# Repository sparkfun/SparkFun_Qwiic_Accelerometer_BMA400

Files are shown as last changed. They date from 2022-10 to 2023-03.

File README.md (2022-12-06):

SparkFun Triple Axis Accelerometer Breakout - BMA400 (Qwiic) 
============================================================

<table class="table table-striped table-bordered"?
  <tr align="center">
    <td><a href="https://www.sparkfun.com/products/21208">SparkFun Triple Axis Accelerometer Breakout - BMA400 (Qwiic)</a></td>
    <td><a href="https://www.sparkfun.com/products/21207">SparkFun Micro Triple Axis Accelerometer Breakout - BMA400 (Qwiic)</a></td>
  </tr>
  <tr align="center">
    <td><a href="https://www.sparkfun.com/products/21208"><i>SparkFun Triple Axis Accelerometer Breakout - BMA400 (Qwiic)</i></a></td>
    <td><a href="https://www.sparkfun.com/products/21207"><i>SparkFun Micro Triple Axis Accelerometer Breakout - BMA400 (Qwiic)</i></a></td>
  </tr>
</table>

The SparkFun Qwiic BMA400 Triple Axis Accelerometer Breakout offers a 3-axis acceleration sensor perfect for ultra-low-power applications on an easy-to-use Qwiic breakout board. Dubbed the first "real" ultra-low power acceleration sensor, the BMA400 is perfect when used in both wearable and smart home applications. Where this sensor shines, however, is its ability to distinguish between critical situations and false signals by avoiding false alarms. The Qwiic system allows for integration into your I<sup>2</sup>C system with no soldering required. This Qwiic breakout also includes 0.1"-spaced PTH pins connected to the sensor's communication interface and interrupt pins for applications that require a traditional soldered connection.

The BMA400 from Bosch Sensortech<sup>&copy;</sup> has a full-scale acceleration range of &plusmn;2/&plusmn;4/&plusmn;8/&plusmn;16g with exceptionally low current consumption of < 14.5&micro;A while operating at its highest performance settings. The sensor also includes a complete feature set for on-chip interrupts including auto wakeup/low power, step counter, activity recognition, orientation detection, and tap/double tap. 

Repository Contents
-------------------
* **/Documents** - Datasheet
* **/Hardware** - Eagle design files (.brd, .sch)
* **/Production** - Production panel files (.brd)

Documentation
-------------
* **[Hookup Guide](https://learn.sparkfun.com/tutorials/sparkfun-triple-axis-accelerometer-breakout---bma400-qwiic-hookup-guide)** - Basic Hookup Guide for the SparkFun Triple Axis Accelerometer Breakout - BMA400 (Qwiic). 
* **[BMA400 Arduino Library](https://github.com/sparkfun/SparkFun_BMA400_Arduino_Library)** - Arduino library for the BMA400 based off the Bosch API.

Product Versions
----------------
* [SEN-21208](https://www.sparkfun.com/products/21208) - Standard Size Initial Release.
* [SEN-21207](https://www.sparkfun.com/products/21207) - Micro Size Initial Release.

License Information
-------------------

This product is _**open source**_! 

Please review the LICENSE.md file for license information.

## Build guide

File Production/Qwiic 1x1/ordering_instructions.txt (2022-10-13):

panel size, 169x117mm
PCB thickness, 1.6mm
number of layers, 2
soldermask color, Red
silkscreen color, White
oz copper, 1oz
finish, HASL lead free
stencils, top
pcs per panel, 24
min trace width, 0.2032mm / 0.0080in
min drill size, 0.3048mm / 0.0120in

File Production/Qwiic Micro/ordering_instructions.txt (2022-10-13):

panel size, 79x170mm
PCB thickness, 1.6mm
number of layers, 2
soldermask color, Red
silkscreen color, White
oz copper, 1oz
finish, HASL lead free
stencils, top
pcs per panel, 64
min trace width, 0.1270mm / 0.0050in
min drill size, 0.3048mm / 0.0120in

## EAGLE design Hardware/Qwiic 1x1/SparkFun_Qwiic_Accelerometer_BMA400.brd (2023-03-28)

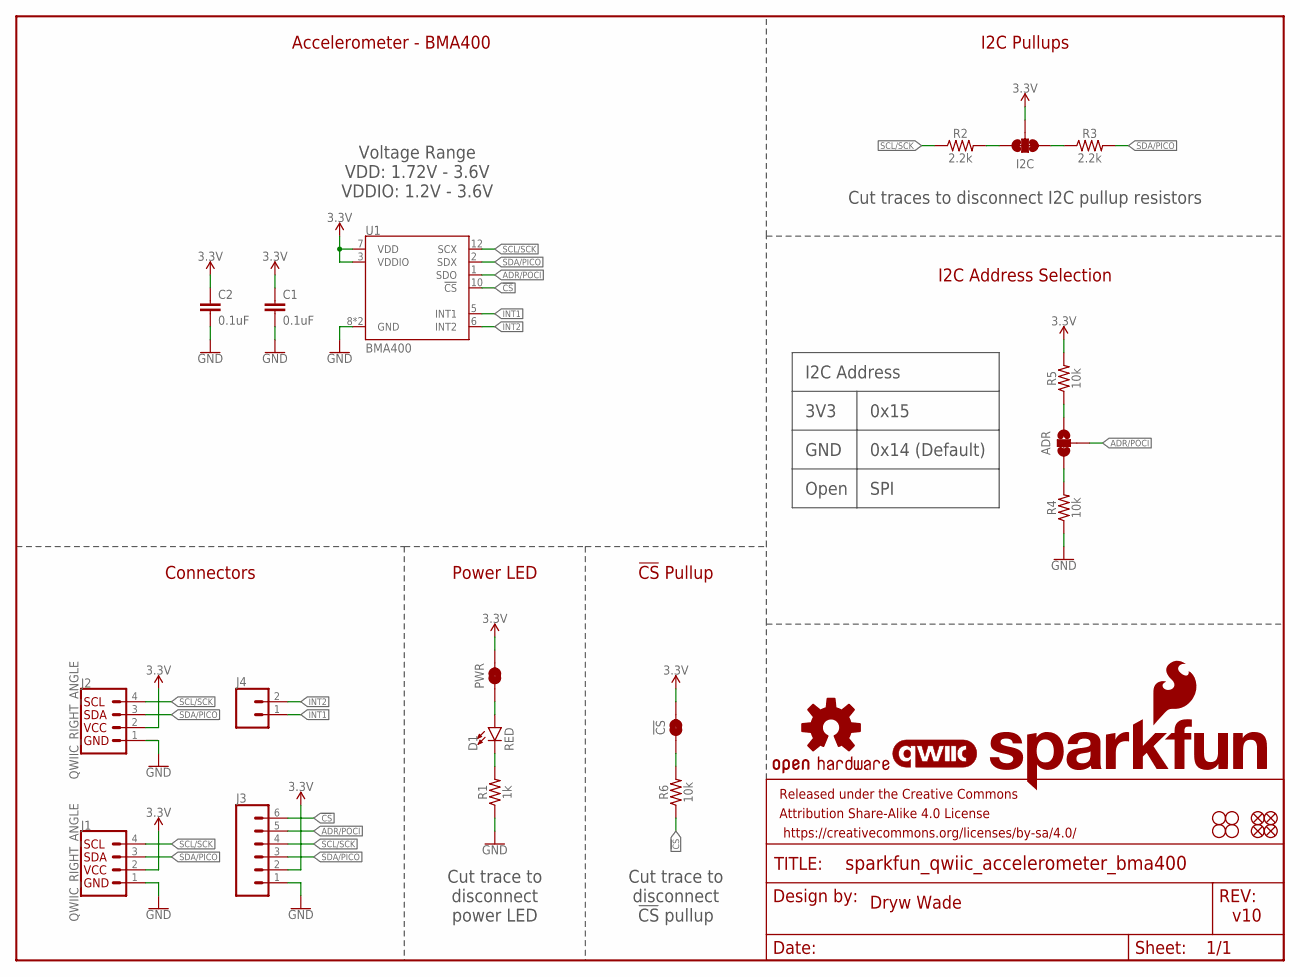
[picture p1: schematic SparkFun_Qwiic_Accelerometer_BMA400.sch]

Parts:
!CS!: JUMPER-SMT_2_NC_TRACE_SILK; SMT-JUMPER_2_NC_TRACE_SILK
ADR: JUMPER-SMT_3_1-NC_TRACE_SILK; SMT-JUMPER_3_1-NC_TRACE_SILK
C1, C2: 0.1uF; 0603
D1: RED; LED-0603
FD1, FD2, FD3, FD4: FIDUCIAL1X2; FIDUCIAL-1X2
FRAME1: FRAME-LETTER; CREATIVE_COMMONS
H1, H2, H3, H4: STAND-OFF
I2C: JUMPER-SMT_3_2-NC_TRACE_SILK; SMT-JUMPER_3_2-NC_TRACE_SILK
J1, J2: QWIIC_RIGHT_ANGLE; JST04_1MM_RA
J3: CONN_06NO_SILK_NO_POP; 1X06_NO_SILK
J4: CONN_021X02_NO_SILK; 1X02_NO_SILK
LOGO1: QWIIC_LOGO_5MM; QWIIC_5MM
LOGO2: SFE_LOGO_NAME_FLAME.1_INCH; SFE_LOGO_NAME_FLAME_.1
LOGO3: OSHW-LOGOS; OSHW-LOGO-S
PWR: JUMPER-SMT_2_NC_TRACE_SILK; SMT-JUMPER_2_NC_TRACE_SILK
R1: 1k; 0603
R2, R3: 2.2k; 0603
R4, R5, R6: 10k; 0603
U1: BMA400

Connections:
3.3V: !CS!.2, C1.1, C2.1, I2C.2, J1.2, J2.2, J3.2, PWR.2, R5.2, U1.3 (VDDIO), U1.7 (VDD)
!CS!: J3.6, R6.1, U1.10 (!CS!)
ADR/POCI: ADR.2, J3.5, U1.1 (SDO)
GND: C1.2, C2.2, J1.1, J2.1, J3.1, R1.1, R4.1, U1.8 (GND), U1.9 (GND)
INT1: J4.1, U1.5 (INT1)
INT2: J4.2, U1.6 (INT2)
unnamed: D1.A, PWR.1
unnamed: D1.C, R1.2
unnamed: I2C.3, R2.2
unnamed: I2C.1, R3.1
unnamed: ADR.1, R5.1
unnamed: ADR.3, R4.2
unnamed: !CS!.1, R6.2
SCL/SCK: J1.4, J2.4, J3.4, R2.1, U1.12 (SCX)
SDA/PICO: J1.3, J2.3, J3.3, R3.2, U1.2 (SDX)

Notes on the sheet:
Dryw Wade
v10
Accelerometer - BMA400
Connectors
Power LED
I2C Pullups
I2C Address Selection
I2C Address
GND
3V3
Open
0x15
0x14 (Default)
SPI
Cut traces to disconnect I2C pullup resistors
Cut trace to disconnect power LED
!CS! Pullup
Cut trace to disconnect !CS! pullup
Voltage Range VDD: 1.72V - 3.6V VDDIO: 1.2V - 3.6V

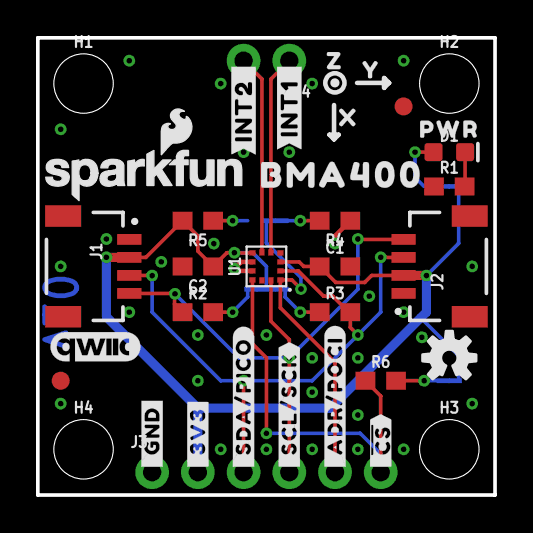
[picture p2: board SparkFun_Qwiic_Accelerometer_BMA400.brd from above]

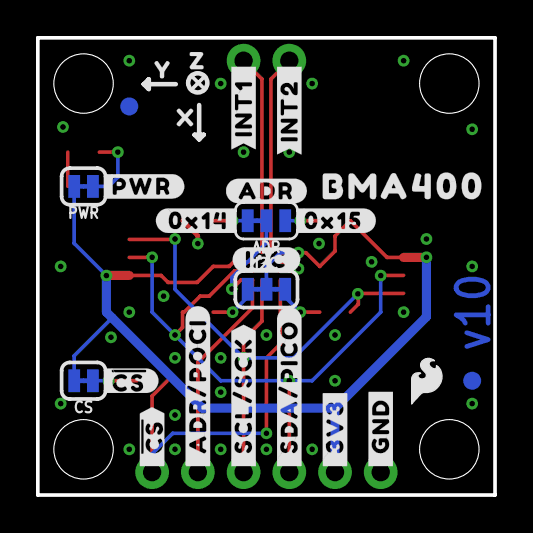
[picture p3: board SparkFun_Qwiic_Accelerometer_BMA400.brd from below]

Board: 2 copper layers, 25.4 x 25.4 mm, 62 parts (25 on the bottom side), 15 nets.

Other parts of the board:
U$1: PWR0
U$2, U$34: X2114
U$3, U$35: Y2115
U$4, U$20: #INT1_#0
U$5, U$21: #INT2_#0
U$6: #_3V3#6
U$7: #_SDA#PICO#5
U$8: #_#CS##2
U$9: #_SCL#SCK#3
U$10: #_GND#0
U$11: #_3V3#0
U$12: #_SDA#PICO#0
U$13: #_SCL#SCK#0
U$14: #_ADR#POCI#0
U$15: #_#CS##0
U$16: #I2C#0
U$17: #ADR#0
U$18: #0X15#0
U$19: #0X14#0
U$22: #PWR#0
U$23, U$24: BMA4000
U$25: ##CS##0
U$26: SFE_LOGO_FLAME_.1
U$27: #_ADR#POCI#1
U$28: #_GND#6
U$29, U$36: Z2116

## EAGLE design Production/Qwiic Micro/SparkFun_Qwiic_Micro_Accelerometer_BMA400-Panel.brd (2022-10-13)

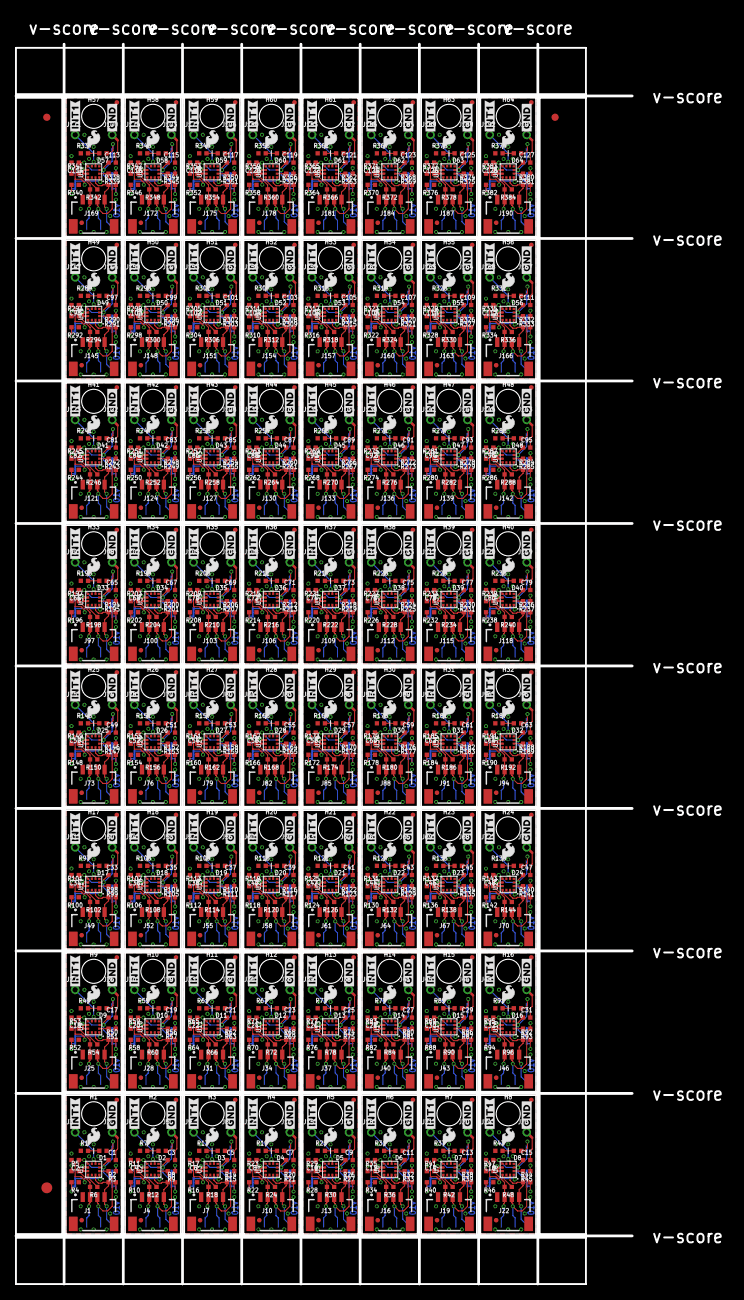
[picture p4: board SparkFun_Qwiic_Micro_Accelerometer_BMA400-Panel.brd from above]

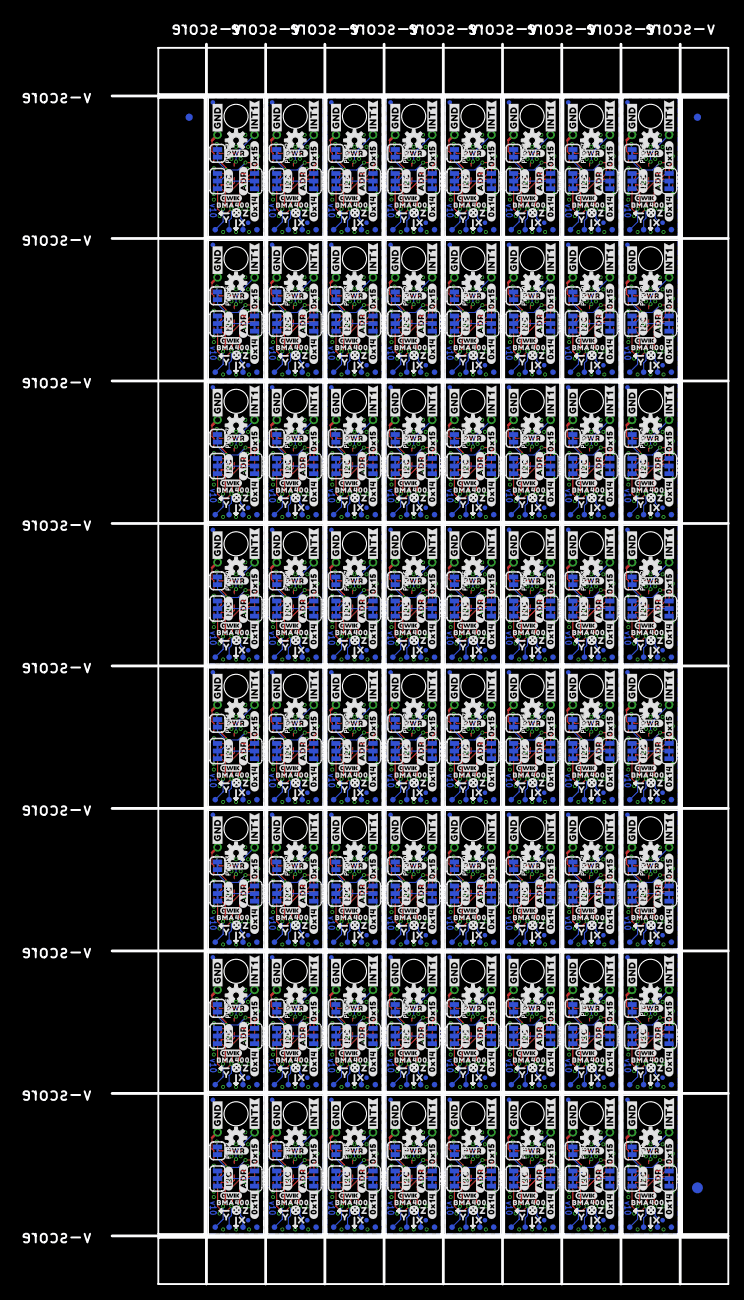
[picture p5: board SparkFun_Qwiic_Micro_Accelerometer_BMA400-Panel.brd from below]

Board: 2 copper layers, 84.6 x 170.2 mm, 2758 parts (1411 on the bottom side), 832 nets.

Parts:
ADR, ADR1, ADR2, ADR3, ADR4, ADR5, ADR6, ADR7, ADR8, ADR9, ADR10, ADR11, ADR12, ADR13, ADR14, ADR15, ADR16, ADR17, ADR18, ADR19, ADR20, ADR21, ADR22, ADR23, ADR24, ADR25, ADR26, ADR27, ADR28, ADR29, ADR30, ADR31, ADR32, ADR33, ADR34, ADR35, ADR36, ADR37, ADR38, ADR39, ADR40, ADR41, ADR42, ADR43, ADR44, ADR45, ADR46, ADR47, ADR48, ADR49, ADR50, ADR51, ADR52, ADR53, ADR54, ADR55, ADR56, ADR57, ADR58, ADR59, ADR60, ADR61, ADR62, ADR63: JUMPER-SMT_3_1-NC_TRACE_SILK; SMT-JUMPER_3_1-NC_TRACE_SILK
C1, C2, C3, C4, C5, C6, C7, C8, C9, C10, C11, C12, C13, C14, C15, C16, C17, C18, C19, C20, C21, C22, C23, C24, C25, C26, C27, C28, C29, C30, C31, C32, C33, C34, C35, C36, C37, C38, C39, C40, C41, C42, C43, C44, C45, C46, C47, C48, C49, C50, C51, C52, C53, C54, C55, C56, C57, C58, C59, C60, C61, C62, C63, C64, C65, C66, C67, C68, C69, C70, C71, C72, C73, C74, C75, C76, C77, C78, C79, C80, C81, C82, C83, C84, C85, C86, C87, C88, C89, C90, C91, C92, C93, C94, C95, C96, C97, C98, C99, C100, C101, C102, C103, C104, C105, C106, C107, C108, C109, C110, C111, C112, C113, C114, C115, C116, C117, C118, C119, C120, C121, C122, C123, C124, C125, C126, C127, C128: 0.1uF; 0402-TIGHT
D1, D2, D3, D4, D5, D6, D7, D8, D9, D10, D11, D12, D13, D14, D15, D16, D17, D18, D19, D20, D21, D22, D23, D24, D25, D26, D27, D28, D29, D30, D31, D32, D33, D34, D35, D36, D37, D38, D39, D40, D41, D42, D43, D44, D45, D46, D47, D48, D49, D50, D51, D52, D53, D54, D55, D56, D57, D58, D59, D60, D61, D62, D63, D64: RED; LED-0402
E$1, E$2, E$3, E$4: FIDUCIAL-1X2
E$5, E$6: FIDUCIAL-1.5X3
FD1, FD2, FD3, FD4, FD5, FD6, FD7, FD8, FD9, FD10, FD11, FD12, FD13, FD14, FD15, FD16, FD17, FD18, FD19, FD20, FD21, FD22, FD23, FD24, FD25, FD26, FD27, FD28, FD29, FD30, FD31, FD32, FD33, FD34, FD35, FD36, FD37, FD38, FD39, FD40, FD41, FD42, FD43, FD44, FD45, FD46, FD47, FD48, FD49, FD50, FD51, FD52, FD53, FD54, FD55, FD56, FD57, FD58, FD59, FD60, FD61, FD62, FD63, FD64, FD65, FD66, FD67, FD68, FD69, FD70, FD71, FD72, FD73, FD74, FD75, FD76, FD77, FD78, FD79, FD80, FD81, FD82, FD83, FD84, FD85, FD86, FD87, FD88, FD89, FD90, FD91, FD92, FD93, FD94, FD95, FD96, FD97, FD98, FD99, FD100, FD101, FD102, FD103, FD104, FD105, FD106, FD107, FD108, FD109, FD110, FD111, FD112, FD113, FD114, FD115, FD116, FD117, FD118, FD119, FD120, FD121, FD122, FD123, FD124, FD125, FD126, FD127, FD128, FD129, FD130, FD131, FD132, FD133, FD134, FD135, FD136, FD137, FD138, FD139, FD140, FD141, FD142, FD143, FD144, FD145, FD146, FD147, FD148, FD149, FD150, FD151, FD152, FD153, FD154, FD155, FD156, FD157, FD158, FD159, FD160, FD161, FD162, FD163, FD164, FD165, FD166, FD167, FD168, FD169, FD170, FD171, FD172, FD173, FD174, FD175, FD176, FD177, FD178, FD179, FD180, FD181, FD182, FD183, FD184, FD185, FD186, FD187, FD188, FD189, FD190, FD191, FD192, FD193, FD194, FD195, FD196, FD197, FD198, FD199, FD200, FD201, FD202, FD203, FD204, FD205, FD206, FD207, FD208, FD209, FD210, FD211, FD212, FD213, FD214, FD215, FD216, FD217, FD218, FD219, FD220, FD221, FD222, FD223, FD224, FD225, FD226, FD227, FD228, FD229, FD230, FD231, FD232, FD233, FD234, FD235, FD236, FD237, FD238, FD239, FD240, FD241, FD242, FD243, FD244, FD245, FD246, FD247, FD248, FD249, FD250, FD251, FD252, FD253, FD254, FD255, FD256: FIDUCIALUFIDUCIAL; FIDUCIAL-MICRO
FRAME1, FRAME2, FRAME3, FRAME4, FRAME5, FRAME6, FRAME7, FRAME8, FRAME9, FRAME10, FRAME11, FRAME12, FRAME13, FRAME14, FRAME15, FRAME16, FRAME17, FRAME18, FRAME19, FRAME20, FRAME21, FRAME22, FRAME23, FRAME24, FRAME25, FRAME26, FRAME27, FRAME28, FRAME29, FRAME30, FRAME31, FRAME32, FRAME33, FRAME34, FRAME35, FRAME36, FRAME37, FRAME38, FRAME39, FRAME40, FRAME41, FRAME42, FRAME43, FRAME44, FRAME45, FRAME46, FRAME47, FRAME48, FRAME49, FRAME50, FRAME51, FRAME52, FRAME53, FRAME54, FRAME55, FRAME56, FRAME57, FRAME58, FRAME59, FRAME60, FRAME61, FRAME62, FRAME63, FRAME64: FRAME-LETTER; CREATIVE_COMMONS
H1, H2, H3, H4, H5, H6, H7, H8, H9, H10, H11, H12, H13, H14, H15, H16, H17, H18, H19, H20, H21, H22, H23, H24, H25, H26, H27, H28, H29, H30, H31, H32, H33, H34, H35, H36, H37, H38, H39, H40, H41, H42, H43, H44, H45, H46, H47, H48, H49, H50, H51, H52, H53, H54, H55, H56, H57, H58, H59, H60, H61, H62, H63, H64: STAND-OFF
I2C, I2C1, I2C2, I2C3, I2C4, I2C5, I2C6, I2C7, I2C8, I2C9, I2C10, I2C11, I2C12, I2C13, I2C14, I2C15, I2C16, I2C17, I2C18, I2C19, I2C20, I2C21, I2C22, I2C23, I2C24, I2C25, I2C26, I2C27, I2C28, I2C29, I2C30, I2C31, I2C32, I2C33, I2C34, I2C35, I2C36, I2C37, I2C38, I2C39, I2C40, I2C41, I2C42, I2C43, I2C44, I2C45, I2C46, I2C47, I2C48, I2C49, I2C50, I2C51, I2C52, I2C53, I2C54, I2C55, I2C56, I2C57, I2C58, I2C59, I2C60, I2C61, I2C62, I2C63: JUMPER-SMT_3_2-NC_TRACE_SILK; SMT-JUMPER_3_2-NC_TRACE_SILK
J1, J4, J7, J10, J13, J16, J19, J22, J25, J28, J31, J34, J37, J40, J43, J46, J49, J52, J55, J58, J61, J64, J67, J70, J73, J76, J79, J82, J85, J88, J91, J94, J97, J100, J103, J106, J109, J112, J115, J118, J121, J124, J127, J130, J133, J136, J139, J142, J145, J148, J151, J154, J157, J160, J163, J166, J169, J172, J175, J178, J181, J184, J187, J190: QWIIC_RIGHT_ANGLE; JST04_1MM_RA
J2, J3, J5, J6, J8, J9, J11, J12, J14, J15, J17, J18, J20, J21, J23, J24, J26, J27, J29, J30, J32, J33, J35, J36, J38, J39, J41, J42, J44, J45, J47, J48, J50, J51, J53, J54, J56, J57, J59, J60, J62, J63, J65, J66, J68, J69, J71, J72, J74, J75, J77, J78, J80, J81, J83, J84, J86, J87, J89, J90, J92, J93, J95, J96, J98, J99, J101, J102, J104, J105, J107, J108, J110, J111, J113, J114, J116, J117, J119, J120, J122, J123, J125, J126, J128, J129, J131, J132, J134, J135, J137, J138, J140, J141, J143, J144, J146, J147, J149, J150, J152, J153, J155, J156, J158, J159, J161, J162, J164, J165, J167, J168, J170, J171, J173, J174, J176, J177, J179, J180, J182, J183, J185, J186, J188, J189, J191, J192: 1X01_1MM_NO_SILK
LOGO1, LOGO5, LOGO9, LOGO13, LOGO17, LOGO21, LOGO25, LOGO29, LOGO33, LOGO37, LOGO41, LOGO45, LOGO49, LOGO53, LOGO57, LOGO61, LOGO65, LOGO69, LOGO73, LOGO77, LOGO81, LOGO85, LOGO89, LOGO93, LOGO97, LOGO101, LOGO105, LOGO109, LOGO113, LOGO117, LOGO121, LOGO125, LOGO129, LOGO133, LOGO137, LOGO141, LOGO145, LOGO149, LOGO153, LOGO157, LOGO161, LOGO165, LOGO169, LOGO173, LOGO177, LOGO181, LOGO185, LOGO189, LOGO193, LOGO197, LOGO201, LOGO205, LOGO209, LOGO213, LOGO217, LOGO221, LOGO225, LOGO229, LOGO233, LOGO237, LOGO241, LOGO245, LOGO249, LOGO253: QWIIC_LOGO_3MM; QWIIC_3MM
LOGO2, LOGO6, LOGO10, LOGO14, LOGO18, LOGO22, LOGO26, LOGO30, LOGO34, LOGO38, LOGO42, LOGO46, LOGO50, LOGO54, LOGO58, LOGO62, LOGO66, LOGO70, LOGO74, LOGO78, LOGO82, LOGO86, LOGO90, LOGO94, LOGO98, LOGO102, LOGO106, LOGO110, LOGO114, LOGO118, LOGO122, LOGO126, LOGO130, LOGO134, LOGO138, LOGO142, LOGO146, LOGO150, LOGO154, LOGO158, LOGO162, LOGO166, LOGO170, LOGO174, LOGO178, LOGO182, LOGO186, LOGO190, LOGO194, LOGO198, LOGO202, LOGO206, LOGO210, LOGO214, LOGO218, LOGO222, LOGO226, LOGO230, LOGO234, LOGO238, LOGO242, LOGO246, LOGO250, LOGO254: SFE_LOGO_NAMEBLANK; BLANK
LOGO3, LOGO7, LOGO11, LOGO15, LOGO19, LOGO23, LOGO27, LOGO31, LOGO35, LOGO39, LOGO43, LOGO47, LOGO51, LOGO55, LOGO59, LOGO63, LOGO67, LOGO71, LOGO75, LOGO79, LOGO83, LOGO87, LOGO91, LOGO95, LOGO99, LOGO103, LOGO107, LOGO111, LOGO115, LOGO119, LOGO123, LOGO127, LOGO131, LOGO135, LOGO139, LOGO143, LOGO147, LOGO151, LOGO155, LOGO159, LOGO163, LOGO167, LOGO171, LOGO175, LOGO179, LOGO183, LOGO187, LOGO191, LOGO195, LOGO199, LOGO203, LOGO207, LOGO211, LOGO215, LOGO219, LOGO223, LOGO227, LOGO231, LOGO235, LOGO239, LOGO243, LOGO247, LOGO251, LOGO255: OSHW-LOGOS; OSHW-LOGO-S
LOGO4, LOGO8, LOGO12, LOGO16, LOGO20, LOGO24, LOGO28, LOGO32, LOGO36, LOGO40, LOGO44, LOGO48, LOGO52, LOGO56, LOGO60, LOGO64, LOGO68, LOGO72, LOGO76, LOGO80, LOGO84, LOGO88, LOGO92, LOGO96, LOGO100, LOGO104, LOGO108, LOGO112, LOGO116, LOGO120, LOGO124, LOGO128, LOGO132, LOGO136, LOGO140, LOGO144, LOGO148, LOGO152, LOGO156, LOGO160, LOGO164, LOGO168, LOGO172, LOGO176, LOGO180, LOGO184, LOGO188, LOGO192, LOGO196, LOGO200, LOGO204, LOGO208, LOGO212, LOGO216, LOGO220, LOGO224, LOGO228, LOGO232, LOGO236, LOGO240, LOGO244, LOGO248, LOGO252, LOGO256: SFE_LOGO_FLAME.1_INCH; SFE_LOGO_FLAME_.1
PWR, PWR1, PWR2, PWR3, PWR4, PWR5, PWR6, PWR7, PWR8, PWR9, PWR10, PWR11, PWR12, PWR13, PWR14, PWR15, PWR16, PWR17, PWR18, PWR19, PWR20, PWR21, PWR22, PWR23, PWR24, PWR25, PWR26, PWR27, PWR28, PWR29, PWR30, PWR31, PWR32, PWR33, PWR34, PWR35, PWR36, PWR37, PWR38, PWR39, PWR40, PWR41, PWR42, PWR43, PWR44, PWR45, PWR46, PWR47, PWR48, PWR49, PWR50, PWR51, PWR52, PWR53, PWR54, PWR55, PWR56, PWR57, PWR58, PWR59, PWR60, PWR61, PWR62, PWR63: JUMPER-SMT_2_NC_TRACE_SILK; SMT-JUMPER_2_NC_TRACE_SILK
R1, R2, R3, R7, R8, R9, R13, R14, R15, R19, R20, R21, R25, R26, R27, R31, R32, R33, R37, R38, R39, R43, R44, R45, R49, R50, R51, R55, R56, R57, R61, R62, R63, R67, R68, R69, R73, R74, R75, R79, R80, R81, R85, R86, R87, R91, R92, R93, R97, R98, R99, R103, R104, R105, R109, R110, R111, R115, R116, R117, R121, R122, R123, R127, R128, R129, R133, R134, R135, R139, R140, R141, R145, R146, R147, R151, R152, R153, R157, R158, R159, R163, R164, R165, R169, R170, R171, R175, R176, R177, R181, R182, R183, R187, R188, R189, R193, R194, R195, R199, R200, R201, R205, R206, R207, R211, R212, R213, R217, R218, R219, R223, R224, R225, R229, R230, R231, R235, R236, R237, R241, R242, R243, R247, R248, R249, R253, R254, R255, R259, R260, R261, R265, R266, R267, R271, R272, R273, R277, R278, R279, R283, R284, R285, R289, R290, R291, R295, R296, R297, R301, R302, R303, R307, R308, R309, R313, R314, R315, R319, R320, R321, R325, R326, R327, R331, R332, R333, R337, R338, R339, R343, R344, R345, R349, R350, R351, R355, R356, R357, R361, R362, R363, R367, R368, R369, R373, R374, R375, R379, R380, R381: 2.2k; 0402-TIGHT
R4, R5, R6, R10, R11, R12, R16, R17, R18, R22, R23, R24, R28, R29, R30, R34, R35, R36, R40, R41, R42, R46, R47, R48, R52, R53, R54, R58, R59, R60, R64, R65, R66, R70, R71, R72, R76, R77, R78, R82, R83, R84, R88, R89, R90, R94, R95, R96, R100, R101, R102, R106, R107, R108, R112, R113, R114, R118, R119, R120, R124, R125, R126, R130, R131, R132, R136, R137, R138, R142, R143, R144, R148, R149, R150, R154, R155, R156, R160, R161, R162, R166, R167, R168, R172, R173, R174, R178, R179, R180, R184, R185, R186, R190, R191, R192, R196, R197, R198, R202, R203, R204, R208, R209, R210, R214, R215, R216, R220, R221, R222, R226, R227, R228, R232, R233, R234, R238, R239, R240, R244, R245, R246, R250, R251, R252, R256, R257, R258, R262, R263, R264, R268, R269, R270, R274, R275, R276, R280, R281, R282, R286, R287, R288, R292, R293, R294, R298, R299, R300, R304, R305, R306, R310, R311, R312, R316, R317, R318, R322, R323, R324, R328, R329, R330, R334, R335, R336, R340, R341, R342, R346, R347, R348, R352, R353, R354, R358, R359, R360, R364, R365, R366, R370, R371, R372, R376, R377, R378, R382, R383, R384: 10k; 0402-TIGHT
TP1, TP2, TP3, TP4, TP5, TP6, TP7, TP8, TP9, TP10, TP11, TP12, TP13, TP14, TP15, TP16, TP17, TP18, TP19, TP20, TP21, TP22, TP23, TP24, TP25, TP26, TP27, TP28, TP29, TP30, TP31, TP32, TP33, TP34, TP35, TP36, TP37, TP38, TP39, TP40, TP41, TP42, TP43, TP44, TP45, TP46, TP47, TP48, TP49, TP50, TP51, TP52, TP53, TP54, TP55, TP56, TP57, TP58, TP59, TP60, TP61, TP62, TP63, TP64, TP65, TP66, TP67, TP68, TP69, TP70, TP71, TP72, TP73, TP74, TP75, TP76, TP77, TP78, TP79, TP80, TP81, TP82, TP83, TP84, TP85, TP86, TP87, TP88, TP89, TP90, TP91, TP92, TP93, TP94, TP95, TP96, TP97, TP98, TP99, TP100, TP101, TP102, TP103, TP104, TP105, TP106, TP107, TP108, TP109, TP110, TP111, TP112, TP113, TP114, TP115, TP116, TP117, TP118, TP119, TP120, TP121, TP122, TP123, TP124, TP125, TP126, TP127, TP128, TP129, TP130, TP131, TP132, TP133, TP134, TP135, TP136, TP137, TP138, TP139, TP140, TP141, TP142, TP143, TP144, TP145, TP146, TP147, TP148, TP149, TP150, TP151, TP152, TP153, TP154, TP155, TP156, TP157, TP158, TP159, TP160, TP161, TP162, TP163, TP164, TP165, TP166, TP167, TP168, TP169, TP170, TP171, TP172, TP173, TP174, TP175, TP176, TP177, TP178, TP179, TP180, TP181, TP182, TP183, TP184, TP185, TP186, TP187, TP188, TP189, TP190, TP191, TP192, TP193, TP194, TP195, TP196, TP197, TP198, TP199, TP200, TP201, TP202, TP203, TP204, TP205, TP206, TP207, TP208, TP209, TP210, TP211, TP212, TP213, TP214, TP215, TP216, TP217, TP218, TP219, TP220, TP221, TP222, TP223, TP224, TP225, TP226, TP227, TP228, TP229, TP230, TP231, TP232, TP233, TP234, TP235, TP236, TP237, TP238, TP239, TP240, TP241, TP242, TP243, TP244, TP245, TP246, TP247, TP248, TP249, TP250, TP251, TP252, TP253, TP254, TP255, TP256: TEST-POINT3; PAD.03X.03
U1, U2, U3, U4, U5, U6, U7, U8, U9, U10, U11, U12, U13, U14, U15, U16, U17, U18, U19, U20, U21, U22, U23, U24, U25, U26, U27, U28, U29, U30, U31, U32, U33, U34, U35, U36, U37, U38, U39, U40, U41, U42, U43, U44, U45, U46, U47, U48, U49, U50, U51, U52, U53, U54, U55, U56, U57, U58, U59, U60, U61, U62, U63, U64: BMA400
U$1, U$4, U$14, U$17, U$27, U$30, U$40, U$43, U$53, U$56, U$66, U$69, U$79, U$82, U$92, U$95, U$105, U$108, U$118, U$121, U$131, U$134, U$144, U$147, U$157, U$160, U$170, U$173, U$183, U$186, U$196, U$199, U$209, U$212, U$222, U$225, U$235, U$238, U$248, U$251, U$261, U$264, U$274, U$277, U$287, U$290, U$300, U$303, U$313, U$316, U$326, U$329, U$339, U$342, U$352, U$355, U$365, U$368, U$378, U$381, U$391, U$394, U$404, U$407, U$417, U$420, U$430, U$433, U$443, U$446, U$456, U$459, U$469, U$472, U$482, U$485, U$495, U$498, U$508, U$511, U$521, U$524, U$534, U$537, U$547, U$550, U$560, U$563, U$573, U$576, U$586, U$589, U$599, U$602, U$612, U$615, U$625, U$628, U$638, U$641, U$651, U$654, U$664, U$667, U$677, U$680, U$690, U$693, U$703, U$706, U$716, U$719, U$729, U$732, U$742, U$745, U$755, U$758, U$768, U$771, U$781, U$784, U$794, U$797, U$807, U$810, U$820, U$823: #INT1#0
U$2, U$3, U$15, U$16, U$28, U$29, U$41, U$42, U$54, U$55, U$67, U$68, U$80, U$81, U$93, U$94, U$106, U$107, U$119, U$120, U$132, U$133, U$145, U$146, U$158, U$159, U$171, U$172, U$184, U$185, U$197, U$198, U$210, U$211, U$223, U$224, U$236, U$237, U$249, U$250, U$262, U$263, U$275, U$276, U$288, U$289, U$301, U$302, U$314, U$315, U$327, U$328, U$340, U$341, U$353, U$354, U$366, U$367, U$379, U$380, U$392, U$393, U$405, U$406, U$418, U$419, U$431, U$432, U$444, U$445, U$457, U$458, U$470, U$471, U$483, U$484, U$496, U$497, U$509, U$510, U$522, U$523, U$535, U$536, U$548, U$549, U$561, U$562, U$574, U$575, U$587, U$588, U$600, U$601, U$613, U$614, U$626, U$627, U$639, U$640, U$652, U$653, U$665, U$666, U$678, U$679, U$691, U$692, U$704, U$705, U$717, U$718, U$730, U$731, U$743, U$744, U$756, U$757, U$769, U$770, U$782, U$783, U$795, U$796, U$808, U$809, U$821, U$822: #GND#0
U$5, U$18, U$31, U$44, U$57, U$70, U$83, U$96, U$109, U$122, U$135, U$148, U$161, U$174, U$187, U$200, U$213, U$226, U$239, U$252, U$265, U$278, U$291, U$304, U$317, U$330, U$343, U$356, U$369, U$382, U$395, U$408, U$421, U$434, U$447, U$460, U$473, U$486, U$499, U$512, U$525, U$538, U$551, U$564, U$577, U$590, U$603, U$616, U$629, U$642, U$655, U$668, U$681, U$694, U$707, U$720, U$733, U$746, U$759, U$772, U$785, U$798, U$811, U$824: BMA4000
U$6, U$24, U$37, U$50, U$63, U$76, U$89, U$102, U$115, U$128, U$141, U$154, U$167, U$180, U$193, U$206, U$219, U$232, U$245, U$258, U$271, U$284, U$297, U$310, U$323, U$336, U$349, U$362, U$375, U$388, U$401, U$414, U$427, U$440, U$453, U$466, U$479, U$492, U$505, U$518, U$531, U$544, U$557, U$570, U$583, U$596, U$609, U$622, U$635, U$648, U$661, U$674, U$687, U$700, U$713, U$726, U$739, U$752, U$765, U$778, U$791, U$804, U$817, U$830: X2114
U$7, U$19, U$32, U$45, U$58, U$71, U$84, U$97, U$110, U$123, U$136, U$149, U$162, U$175, U$188, U$201, U$214, U$227, U$240, U$253, U$266, U$279, U$292, U$305, U$318, U$331, U$344, U$357, U$370, U$383, U$396, U$409, U$422, U$435, U$448, U$461, U$474, U$487, U$500, U$513, U$526, U$539, U$552, U$565, U$578, U$591, U$604, U$617, U$630, U$643, U$656, U$669, U$682, U$695, U$708, U$721, U$734, U$747, U$760, U$773, U$786, U$799, U$812, U$825: #I2C#0
U$8, U$20, U$33, U$46, U$59, U$72, U$85, U$98, U$111, U$124, U$137, U$150, U$163, U$176, U$189, U$202, U$215, U$228, U$241, U$254, U$267, U$280, U$293, U$306, U$319, U$332, U$345, U$358, U$371, U$384, U$397, U$410, U$423, U$436, U$449, U$462, U$475, U$488, U$501, U$514, U$527, U$540, U$553, U$566, U$579, U$592, U$605, U$618, U$631, U$644, U$657, U$670, U$683, U$696, U$709, U$722, U$735, U$748, U$761, U$774, U$787, U$800, U$813, U$826: #ADR#0
U$9, U$21, U$34, U$47, U$60, U$73, U$86, U$99, U$112, U$125, U$138, U$151, U$164, U$177, U$190, U$203, U$216, U$229, U$242, U$255, U$268, U$281, U$294, U$307, U$320, U$333, U$346, U$359, U$372, U$385, U$398, U$411, U$424, U$437, U$450, U$463, U$476, U$489, U$502, U$515, U$528, U$541, U$554, U$567, U$580, U$593, U$606, U$619, U$632, U$645, U$658, U$671, U$684, U$697, U$710, U$723, U$736, U$749, U$762, U$775, U$788, U$801, U$814, U$827: #0X15#0
U$10, U$22, U$35, U$48, U$61, U$74, U$87, U$100, U$113, U$126, U$139, U$152, U$165, U$178, U$191, U$204, U$217, U$230, U$243, U$256, U$269, U$282, U$295, U$308, U$321, U$334, U$347, U$360, U$373, U$386, U$399, U$412, U$425, U$438, U$451, U$464, U$477, U$490, U$503, U$516, U$529, U$542, U$555, U$568, U$581, U$594, U$607, U$620, U$633, U$646, U$659, U$672, U$685, U$698, U$711, U$724, U$737, U$750, U$763, U$776, U$789, U$802, U$815, U$828: #0X14#0
U$11, U$23, U$36, U$49, U$62, U$75, U$88, U$101, U$114, U$127, U$140, U$153, U$166, U$179, U$192, U$205, U$218, U$231, U$244, U$257, U$270, U$283, U$296, U$309, U$322, U$335, U$348, U$361, U$374, U$387, U$400, U$413, U$426, U$439, U$452, U$465, U$478, U$491, U$504, U$517, U$530, U$543, U$556, U$569, U$582, U$595, U$608, U$621, U$634, U$647, U$660, U$673, U$686, U$699, U$712, U$725, U$738, U$751, U$764, U$777, U$790, U$803, U$816, U$829: #PWR#0
U$12, U$25, U$38, U$51, U$64, U$77, U$90, U$103, U$116, U$129, U$142, U$155, U$168, U$181, U$194, U$207, U$220, U$233, U$246, U$259, U$272, U$285, U$298, U$311, U$324, U$337, U$350, U$363, U$376, U$389, U$402, U$415, U$428, U$441, U$454, U$467, U$480, U$493, U$506, U$519, U$532, U$545, U$558, U$571, U$584, U$597, U$610, U$623, U$636, U$649, U$662, U$675, U$688, U$701, U$714, U$727, U$740, U$753, U$766, U$779, U$792, U$805, U$818, U$831: Y2115
U$13, U$26, U$39, U$52, U$65, U$78, U$91, U$104, U$117, U$130, U$143, U$156, U$169, U$182, U$195, U$208, U$221, U$234, U$247, U$260, U$273, U$286, U$299, U$312, U$325, U$338, U$351, U$364, U$377, U$390, U$403, U$416, U$429, U$442, U$455, U$468, U$481, U$494, U$507, U$520, U$533, U$546, U$559, U$572, U$585, U$598, U$611, U$624, U$637, U$650, U$663, U$676, U$689, U$702, U$715, U$728, U$741, U$754, U$767, U$780, U$793, U$806, U$819, U$832: Z2116

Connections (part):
3.3V: C1.1, C2.1, I2C.2, J1.2, PWR.2, R5.2, R6.2, TP2.1, U1.3, U1.7
3.3V1: C3.1, C4.1, I2C1.2, J4.2, PWR1.2, R11.2, R12.2, TP6.1, U2.3, U2.7
3.3V2: C5.1, C6.1, I2C2.2, J7.2, PWR2.2, R17.2, R18.2, TP10.1, U3.3, U3.7
3.3V3: C7.1, C8.1, I2C3.2, J10.2, PWR3.2, R23.2, R24.2, TP14.1, U4.3, U4.7
3.3V4: C9.1, C10.1, I2C4.2, J13.2, PWR4.2, R29.2, R30.2, TP18.1, U5.3, U5.7
3.3V5: C11.1, C12.1, I2C5.2, J16.2, PWR5.2, R35.2, R36.2, TP22.1, U6.3, U6.7
3.3V6: C13.1, C14.1, I2C6.2, J19.2, PWR6.2, R41.2, R42.2, TP26.1, U7.3, U7.7
3.3V7: C15.1, C16.1, I2C7.2, J22.2, PWR7.2, R47.2, R48.2, TP30.1, U8.3, U8.7
3.3V8: C17.1, C18.1, I2C8.2, J25.2, PWR8.2, R53.2, R54.2, TP34.1, U9.3, U9.7
3.3V9: C19.1, C20.1, I2C9.2, J28.2, PWR9.2, R59.2, R60.2, TP38.1, U10.3, U10.7
3.3V10: C21.1, C22.1, I2C10.2, J31.2, PWR10.2, R65.2, R66.2, TP42.1, U11.3, U11.7
3.3V11: C23.1, C24.1, I2C11.2, J34.2, PWR11.2, R71.2, R72.2, TP46.1, U12.3, U12.7
3.3V12: C25.1, C26.1, I2C12.2, J37.2, PWR12.2, R77.2, R78.2, TP50.1, U13.3, U13.7
3.3V13: C27.1, C28.1, I2C13.2, J40.2, PWR13.2, R83.2, R84.2, TP54.1, U14.3, U14.7
3.3V14: C29.1, C30.1, I2C14.2, J43.2, PWR14.2, R89.2, R90.2, TP58.1, U15.3, U15.7
3.3V15: C31.1, C32.1, I2C15.2, J46.2, PWR15.2, R95.2, R96.2, TP62.1, U16.3, U16.7
3.3V16: C33.1, C34.1, I2C16.2, J49.2, PWR16.2, R101.2, R102.2, TP66.1, U17.3, U17.7
3.3V17: C35.1, C36.1, I2C17.2, J52.2, PWR17.2, R107.2, R108.2, TP70.1, U18.3, U18.7
3.3V18: C37.1, C38.1, I2C18.2, J55.2, PWR18.2, R113.2, R114.2, TP74.1, U19.3, U19.7
3.3V19: C39.1, C40.1, I2C19.2, J58.2, PWR19.2, R119.2, R120.2, TP78.1, U20.3, U20.7
3.3V20: C41.1, C42.1, I2C20.2, J61.2, PWR20.2, R125.2, R126.2, TP82.1, U21.3, U21.7
3.3V21: C43.1, C44.1, I2C21.2, J64.2, PWR21.2, R131.2, R132.2, TP86.1, U22.3, U22.7
3.3V22: C45.1, C46.1, I2C22.2, J67.2, PWR22.2, R137.2, R138.2, TP90.1, U23.3, U23.7
3.3V23: C47.1, C48.1, I2C23.2, J70.2, PWR23.2, R143.2, R144.2, TP94.1, U24.3, U24.7
3.3V24: C49.1, C50.1, I2C24.2, J73.2, PWR24.2, R149.2, R150.2, TP98.1, U25.3, U25.7
3.3V25: C51.1, C52.1, I2C25.2, J76.2, PWR25.2, R155.2, R156.2, TP102.1, U26.3, U26.7
3.3V26: C53.1, C54.1, I2C26.2, J79.2, PWR26.2, R161.2, R162.2, TP106.1, U27.3, U27.7
3.3V27: C55.1, C56.1, I2C27.2, J82.2, PWR27.2, R167.2, R168.2, TP110.1, U28.3, U28.7
3.3V28: C57.1, C58.1, I2C28.2, J85.2, PWR28.2, R173.2, R174.2, TP114.1, U29.3, U29.7
3.3V29: C59.1, C60.1, I2C29.2, J88.2, PWR29.2, R179.2, R180.2, TP118.1, U30.3, U30.7
3.3V30: C61.1, C62.1, I2C30.2, J91.2, PWR30.2, R185.2, R186.2, TP122.1, U31.3, U31.7
3.3V31: C63.1, C64.1, I2C31.2, J94.2, PWR31.2, R191.2, R192.2, TP126.1, U32.3, U32.7
3.3V32: C65.1, C66.1, I2C32.2, J97.2, PWR32.2, R197.2, R198.2, TP130.1, U33.3, U33.7
3.3V33: C67.1, C68.1, I2C33.2, J100.2, PWR33.2, R203.2, R204.2, TP134.1, U34.3, U34.7
3.3V34: C69.1, C70.1, I2C34.2, J103.2, PWR34.2, R209.2, R210.2, TP138.1, U35.3, U35.7
3.3V35: C71.1, C72.1, I2C35.2, J106.2, PWR35.2, R215.2, R216.2, TP142.1, U36.3, U36.7
3.3V36: C73.1, C74.1, I2C36.2, J109.2, PWR36.2, R221.2, R222.2, TP146.1, U37.3, U37.7
3.3V37: C75.1, C76.1, I2C37.2, J112.2, PWR37.2, R227.2, R228.2, TP150.1, U38.3, U38.7
3.3V38: C77.1, C78.1, I2C38.2, J115.2, PWR38.2, R233.2, R234.2, TP154.1, U39.3, U39.7
3.3V39: C79.1, C80.1, I2C39.2, J118.2, PWR39.2, R239.2, R240.2, TP158.1, U40.3, U40.7
3.3V40: C81.1, C82.1, I2C40.2, J121.2, PWR40.2, R245.2, R246.2, TP162.1, U41.3, U41.7
3.3V41: C83.1, C84.1, I2C41.2, J124.2, PWR41.2, R251.2, R252.2, TP166.1, U42.3, U42.7
3.3V42: C85.1, C86.1, I2C42.2, J127.2, PWR42.2, R257.2, R258.2, TP170.1, U43.3, U43.7
3.3V43: C87.1, C88.1, I2C43.2, J130.2, PWR43.2, R263.2, R264.2, TP174.1, U44.3, U44.7
3.3V44: C89.1, C90.1, I2C44.2, J133.2, PWR44.2, R269.2, R270.2, TP178.1, U45.3, U45.7
3.3V45: C91.1, C92.1, I2C45.2, J136.2, PWR45.2, R275.2, R276.2, TP182.1, U46.3, U46.7
3.3V46: C93.1, C94.1, I2C46.2, J139.2, PWR46.2, R281.2, R282.2, TP186.1, U47.3, U47.7
3.3V47: C95.1, C96.1, I2C47.2, J142.2, PWR47.2, R287.2, R288.2, TP190.1, U48.3, U48.7
3.3V48: C97.1, C98.1, I2C48.2, J145.2, PWR48.2, R293.2, R294.2, TP194.1, U49.3, U49.7
3.3V49: C99.1, C100.1, I2C49.2, J148.2, PWR49.2, R299.2, R300.2, TP198.1, U50.3, U50.7
3.3V50: C101.1, C102.1, I2C50.2, J151.2, PWR50.2, R305.2, R306.2, TP202.1, U51.3, U51.7
3.3V51: C103.1, C104.1, I2C51.2, J154.2, PWR51.2, R311.2, R312.2, TP206.1, U52.3, U52.7
3.3V52: C105.1, C106.1, I2C52.2, J157.2, PWR52.2, R317.2, R318.2, TP210.1, U53.3, U53.7
3.3V53: C107.1, C108.1, I2C53.2, J160.2, PWR53.2, R323.2, R324.2, TP214.1, U54.3, U54.7
3.3V54: C109.1, C110.1, I2C54.2, J163.2, PWR54.2, R329.2, R330.2, TP218.1, U55.3, U55.7
3.3V55: C111.1, C112.1, I2C55.2, J166.2, PWR55.2, R335.2, R336.2, TP222.1, U56.3, U56.7
3.3V56: C113.1, C114.1, I2C56.2, J169.2, PWR56.2, R341.2, R342.2, TP226.1, U57.3, U57.7
3.3V57: C115.1, C116.1, I2C57.2, J172.2, PWR57.2, R347.2, R348.2, TP230.1, U58.3, U58.7
3.3V58: C117.1, C118.1, I2C58.2, J175.2, PWR58.2, R353.2, R354.2, TP234.1, U59.3, U59.7
3.3V59: C119.1, C120.1, I2C59.2, J178.2, PWR59.2, R359.2, R360.2, TP238.1, U60.3, U60.7
3.3V60: C121.1, C122.1, I2C60.2, J181.2, PWR60.2, R365.2, R366.2, TP242.1, U61.3, U61.7
3.3V61: C123.1, C124.1, I2C61.2, J184.2, PWR61.2, R371.2, R372.2, TP246.1, U62.3, U62.7
3.3V62: C125.1, C126.1, I2C62.2, J187.2, PWR62.2, R377.2, R378.2, TP250.1, U63.3, U63.7
3.3V63: C127.1, C128.1, I2C63.2, J190.2, PWR63.2, R383.2, R384.2, TP254.1, U64.3, U64.7
!CS!: R6.1, U1.10
!CS!1: R12.1, U2.10
!CS!2: R18.1, U3.10
!CS!3: R24.1, U4.10
!CS!4: R30.1, U5.10
!CS!5: R36.1, U6.10
!CS!6: R42.1, U7.10
!CS!7: R48.1, U8.10
!CS!8: R54.1, U9.10
!CS!9: R60.1, U10.10
!CS!10: R66.1, U11.10
!CS!11: R72.1, U12.10
!CS!12: R78.1, U13.10
!CS!13: R84.1, U14.10
!CS!14: R90.1, U15.10
!CS!15: R96.1, U16.10
!CS!16: R102.1, U17.10
!CS!17: R108.1, U18.10
!CS!18: R114.1, U19.10
!CS!19: R120.1, U20.10
!CS!20: R126.1, U21.10
!CS!21: R132.1, U22.10
!CS!22: R138.1, U23.10
!CS!23: R144.1, U24.10
!CS!24: R150.1, U25.10
!CS!25: R156.1, U26.10
!CS!26: R162.1, U27.10
!CS!27: R168.1, U28.10
!CS!28: R174.1, U29.10
!CS!29: R180.1, U30.10
!CS!30: R186.1, U31.10
!CS!31: R192.1, U32.10
!CS!32: R198.1, U33.10
!CS!33: R204.1, U34.10
!CS!34: R210.1, U35.10
!CS!35: R216.1, U36.10
!CS!36: R222.1, U37.10
!CS!37: R228.1, U38.10
!CS!38: R234.1, U39.10
!CS!39: R240.1, U40.10
!CS!40: R246.1, U41.10
!CS!41: R252.1, U42.10
!CS!42: R258.1, U43.10
!CS!43: R264.1, U44.10
!CS!44: R270.1, U45.10
!CS!45: R276.1, U46.10
!CS!46: R282.1, U47.10
!CS!47: R288.1, U48.10
!CS!48: R294.1, U49.10
!CS!49: R300.1, U50.10
!CS!50: R306.1, U51.10
!CS!51: R312.1, U52.10
!CS!52: R318.1, U53.10
!CS!53: R324.1, U54.10
!CS!54: R330.1, U55.10
!CS!55: R336.1, U56.10
!CS!56: R342.1, U57.10
!CS!57: R348.1, U58.10
!CS!58: R354.1, U59.10
!CS!59: R360.1, U60.10
!CS!60: R366.1, U61.10
!CS!61: R372.1, U62.10
!CS!62: R378.1, U63.10
!CS!63: R384.1, U64.10
ADR: ADR.2, U1.1
ADR1: ADR1.2, U2.1
ADR2: ADR2.2, U3.1
ADR3: ADR3.2, U4.1
ADR4: ADR4.2, U5.1
ADR5: ADR5.2, U6.1
ADR6: ADR6.2, U7.1
ADR7: ADR7.2, U8.1
ADR8: ADR8.2, U9.1
ADR9: ADR9.2, U10.1
ADR10: ADR10.2, U11.1
ADR11: ADR11.2, U12.1
ADR12: ADR12.2, U13.1
ADR13: ADR13.2, U14.1
ADR14: ADR14.2, U15.1
ADR15: ADR15.2, U16.1
ADR16: ADR16.2, U17.1
ADR17: ADR17.2, U18.1
ADR18: ADR18.2, U19.1
ADR19: ADR19.2, U20.1
ADR20: ADR20.2, U21.1
ADR21: ADR21.2, U22.1
ADR22: ADR22.2, U23.1
ADR23: ADR23.2, U24.1
ADR24: ADR24.2, U25.1
ADR25: ADR25.2, U26.1
ADR26: ADR26.2, U27.1
ADR27: ADR27.2, U28.1
ADR28: ADR28.2, U29.1
ADR29: ADR29.2, U30.1
ADR30: ADR30.2, U31.1
ADR31: ADR31.2, U32.1
ADR32: ADR32.2, U33.1
ADR33: ADR33.2, U34.1
ADR34: ADR34.2, U35.1
ADR35: ADR35.2, U36.1
ADR36: ADR36.2, U37.1
ADR37: ADR37.2, U38.1
ADR38: ADR38.2, U39.1
ADR39: ADR39.2, U40.1
ADR40: ADR40.2, U41.1
ADR41: ADR41.2, U42.1
ADR42: ADR42.2, U43.1
ADR43: ADR43.2, U44.1
ADR44: ADR44.2, U45.1
ADR45: ADR45.2, U46.1
ADR46: ADR46.2, U47.1
ADR47: ADR47.2, U48.1
ADR48: ADR48.2, U49.1
ADR49: ADR49.2, U50.1
ADR50: ADR50.2, U51.1
ADR51: ADR51.2, U52.1
ADR52: ADR52.2, U53.1
ADR53: ADR53.2, U54.1
ADR54: ADR54.2, U55.1
ADR55: ADR55.2, U56.1
ADR56: ADR56.2, U57.1
ADR57: ADR57.2, U58.1
ADR58: ADR58.2, U59.1
ADR59: ADR59.2, U60.1
ADR60: ADR60.2, U61.1
ADR61: ADR61.2, U62.1
ADR62: ADR62.2, U63.1
ADR63: ADR63.2, U64.1
GND: C1.2, C2.2, J1.1, J2.1, R1.1, R4.1, TP1.1, U1.8, U1.9
GND1: C3.2, C4.2, J4.1, J5.1, R7.1, R10.1, TP5.1, U2.8, U2.9
GND2: C5.2, C6.2, J7.1, J8.1, R13.1, R16.1, TP9.1, U3.8, U3.9
GND3: C7.2, C8.2, J10.1, J11.1, R19.1, R22.1, TP13.1, U4.8, U4.9
GND4: C9.2, C10.2, J13.1, J14.1, R25.1, R28.1, TP17.1, U5.8, U5.9
GND5: C11.2, C12.2, J16.1, J17.1, R31.1, R34.1, TP21.1, U6.8, U6.9
GND6: C13.2, C14.2, J19.1, J20.1, R37.1, R40.1, TP25.1, U7.8, U7.9
GND7: C15.2, C16.2, J22.1, J23.1, R43.1, R46.1, TP29.1, U8.8, U8.9
GND8: C17.2, C18.2, J25.1, J26.1, R49.1, R52.1, TP33.1, U9.8, U9.9
GND9: C19.2, C20.2, J28.1, J29.1, R55.1, R58.1, TP37.1, U10.8, U10.9
GND10: C21.2, C22.2, J31.1, J32.1, R61.1, R64.1, TP41.1, U11.8, U11.9
GND11: C23.2, C24.2, J34.1, J35.1, R67.1, R70.1, TP45.1, U12.8, U12.9
GND12: C25.2, C26.2, J37.1, J38.1, R73.1, R76.1, TP49.1, U13.8, U13.9
GND13: C27.2, C28.2, J40.1, J41.1, R79.1, R82.1, TP53.1, U14.8, U14.9
GND14: C29.2, C30.2, J43.1, J44.1, R85.1, R88.1, TP57.1, U15.8, U15.9
GND15: C31.2, C32.2, J46.1, J47.1, R91.1, R94.1, TP61.1, U16.8, U16.9
GND16: C33.2, C34.2, J49.1, J50.1, R97.1, R100.1, TP65.1, U17.8, U17.9
GND17: C35.2, C36.2, J52.1, J53.1, R103.1, R106.1, TP69.1, U18.8, U18.9
GND18: C37.2, C38.2, J55.1, J56.1, R109.1, R112.1, TP73.1, U19.8, U19.9
GND19: C39.2, C40.2, J58.1, J59.1, R115.1, R118.1, TP77.1, U20.8, U20.9
GND20: C41.2, C42.2, J61.1, J62.1, R121.1, R124.1, TP81.1, U21.8, U21.9
GND21: C43.2, C44.2, J64.1, J65.1, R127.1, R130.1, TP85.1, U22.8, U22.9
GND22: C45.2, C46.2, J67.1, J68.1, R133.1, R136.1, TP89.1, U23.8, U23.9
GND23: C47.2, C48.2, J70.1, J71.1, R139.1, R142.1, TP93.1, U24.8, U24.9
GND24: C49.2, C50.2, J73.1, J74.1, R145.1, R148.1, TP97.1, U25.8, U25.9
GND25: C51.2, C52.2, J76.1, J77.1, R151.1, R154.1, TP101.1, U26.8, U26.9
GND26: C53.2, C54.2, J79.1, J80.1, R157.1, R160.1, TP105.1, U27.8, U27.9
GND27: C55.2, C56.2, J82.1, J83.1, R163.1, R166.1, TP109.1, U28.8, U28.9
GND28: C57.2, C58.2, J85.1, J86.1, R169.1, R172.1, TP113.1, U29.8, U29.9
GND29: C59.2, C60.2, J88.1, J89.1, R175.1, R178.1, TP117.1, U30.8, U30.9
GND30: C61.2, C62.2, J91.1, J92.1, R181.1, R184.1, TP121.1, U31.8, U31.9
GND31: C63.2, C64.2, J94.1, J95.1, R187.1, R190.1, TP125.1, U32.8, U32.9
GND32: C65.2, C66.2, J97.1, J98.1, R193.1, R196.1, TP129.1, U33.8, U33.9
GND33: C67.2, C68.2, J100.1, J101.1, R199.1, R202.1, TP133.1, U34.8, U34.9
GND34: C69.2, C70.2, J103.1, J104.1, R205.1, R208.1, TP137.1, U35.8, U35.9
GND35: C71.2, C72.2, J106.1, J107.1, R211.1, R214.1, TP141.1, U36.8, U36.9
GND36: C73.2, C74.2, J109.1, J110.1, R217.1, R220.1, TP145.1, U37.8, U37.9
GND37: C75.2, C76.2, J112.1, J113.1, R223.1, R226.1, TP149.1, U38.8, U38.9
GND38: C77.2, C78.2, J115.1, J116.1, R229.1, R232.1, TP153.1, U39.8, U39.9
GND39: C79.2, C80.2, J118.1, J119.1, R235.1, R238.1, TP157.1, U40.8, U40.9
GND40: C81.2, C82.2, J121.1, J122.1, R241.1, R244.1, TP161.1, U41.8, U41.9
GND41: C83.2, C84.2, J124.1, J125.1, R247.1, R250.1, TP165.1, U42.8, U42.9
GND42: C85.2, C86.2, J127.1, J128.1, R253.1, R256.1, TP169.1, U43.8, U43.9
GND43: C87.2, C88.2, J130.1, J131.1, R259.1, R262.1, TP173.1, U44.8, U44.9
GND44: C89.2, C90.2, J133.1, J134.1, R265.1, R268.1, TP177.1, U45.8, U45.9
GND45: C91.2, C92.2, J136.1, J137.1, R271.1, R274.1, TP181.1, U46.8, U46.9
GND46: C93.2, C94.2, J139.1, J140.1, R277.1, R280.1, TP185.1, U47.8, U47.9
GND47: C95.2, C96.2, J142.1, J143.1, R283.1, R286.1, TP189.1, U48.8, U48.9
GND48: C97.2, C98.2, J145.1, J146.1, R289.1, R292.1, TP193.1, U49.8, U49.9
GND49: C99.2, C100.2, J148.1, J149.1, R295.1, R298.1, TP197.1, U50.8, U50.9
GND50: C101.2, C102.2, J151.1, J152.1, R301.1, R304.1, TP201.1, U51.8, U51.9
GND51: C103.2, C104.2, J154.1, J155.1, R307.1, R310.1, TP205.1, U52.8, U52.9
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

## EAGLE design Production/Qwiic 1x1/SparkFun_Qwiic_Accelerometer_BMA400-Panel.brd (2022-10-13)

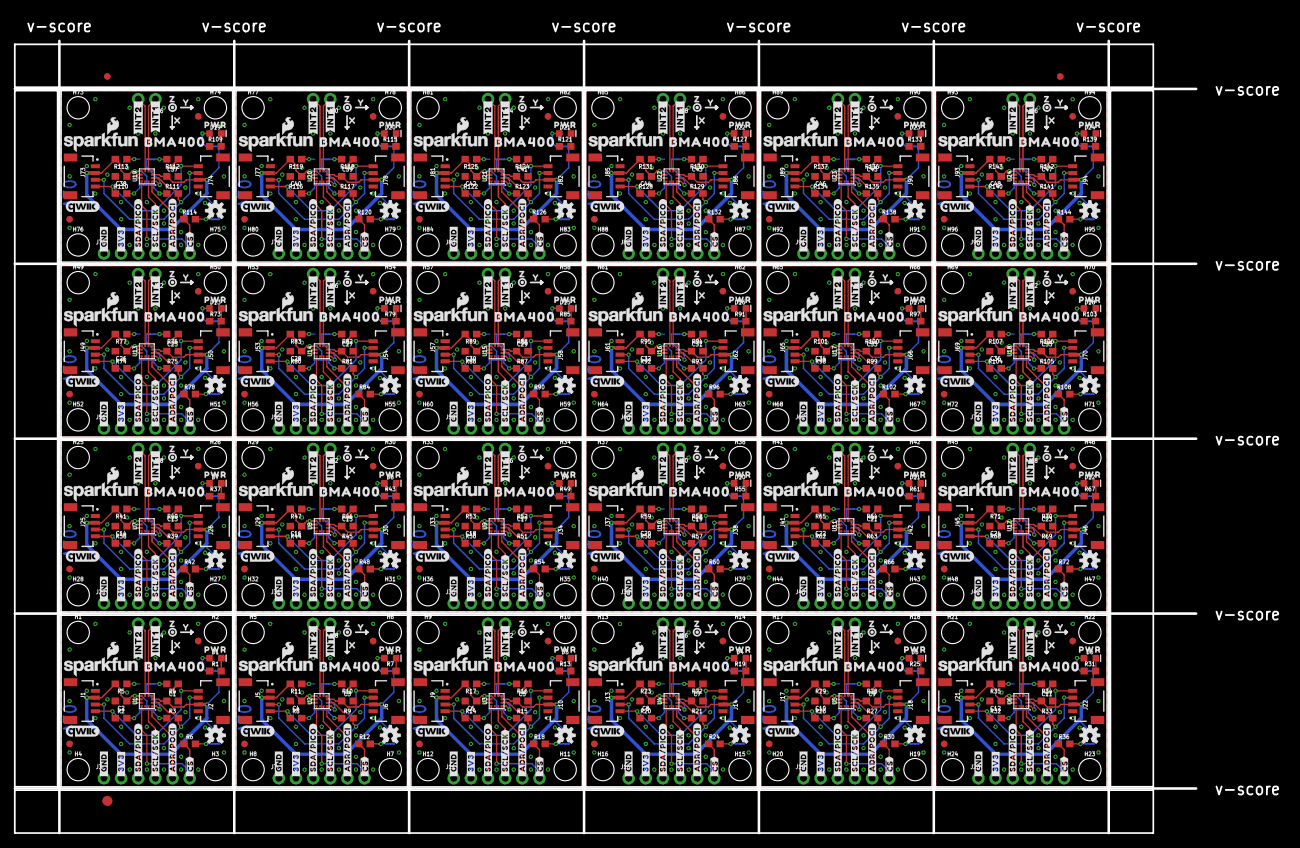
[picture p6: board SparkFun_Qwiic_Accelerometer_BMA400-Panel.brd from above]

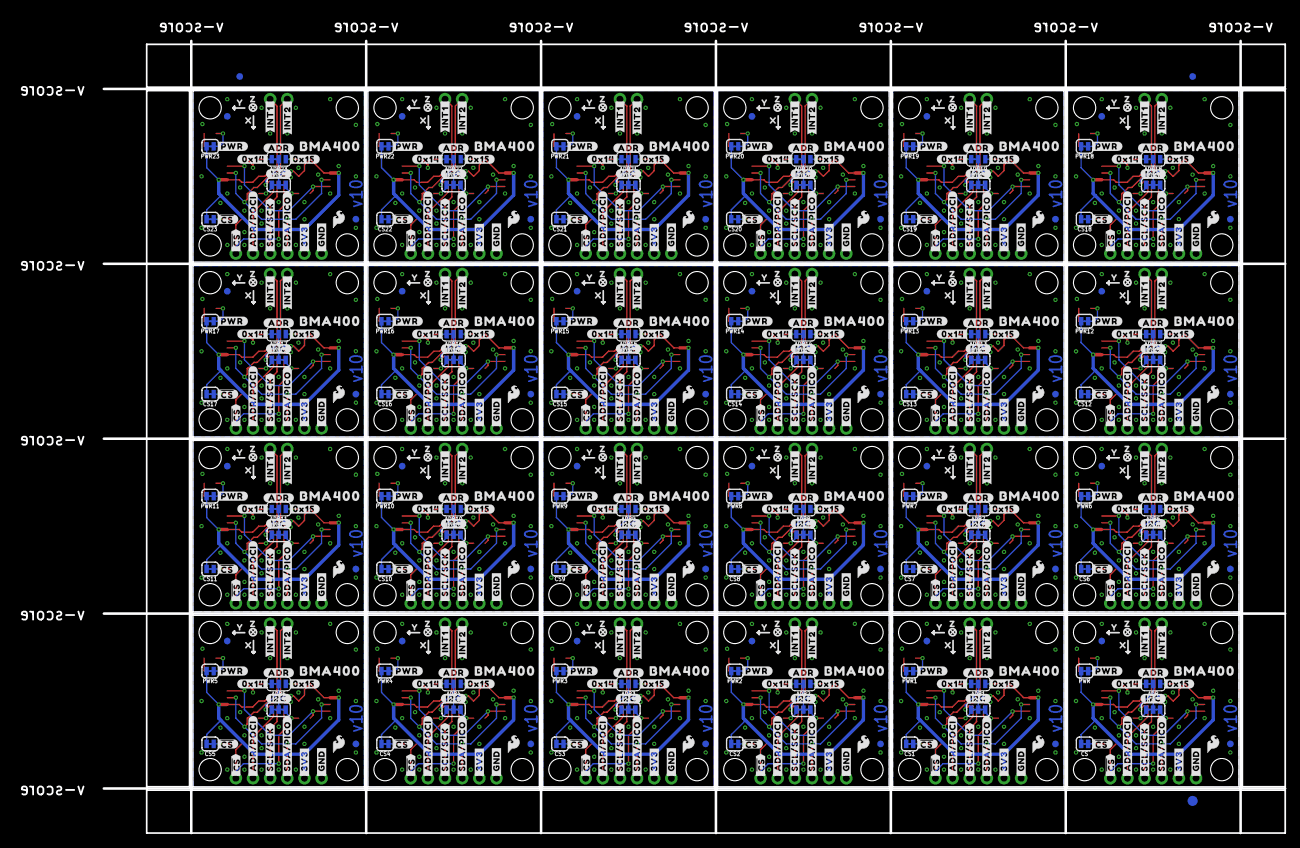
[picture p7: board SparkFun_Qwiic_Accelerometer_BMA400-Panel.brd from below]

Board: 2 copper layers, 175.0 x 117.3 mm, 1470 parts (603 on the bottom side), 360 nets.

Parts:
!CS!, !CS!1, !CS!2, !CS!3, !CS!4, !CS!5, !CS!6, !CS!7, !CS!8, !CS!9, !CS!10, !CS!11, !CS!12, !CS!13, !CS!14, !CS!15, !CS!16, !CS!17, !CS!18, !CS!19, !CS!20, !CS!21, !CS!22, !CS!23: JUMPER-SMT_2_NC_TRACE_SILK; SMT-JUMPER_2_NC_TRACE_SILK
ADR, ADR1, ADR2, ADR3, ADR4, ADR5, ADR6, ADR7, ADR8, ADR9, ADR10, ADR11, ADR12, ADR13, ADR14, ADR15, ADR16, ADR17, ADR18, ADR19, ADR20, ADR21, ADR22, ADR23: JUMPER-SMT_3_1-NC_TRACE_SILK; SMT-JUMPER_3_1-NC_TRACE_SILK
C1, C2, C3, C4, C5, C6, C7, C8, C9, C10, C11, C12, C13, C14, C15, C16, C17, C18, C19, C20, C21, C22, C23, C24, C25, C26, C27, C28, C29, C30, C31, C32, C33, C34, C35, C36, C37, C38, C39, C40, C41, C42, C43, C44, C45, C46, C47, C48: 0.1uF; 0603
D1, D2, D3, D4, D5, D6, D7, D8, D9, D10, D11, D12, D13, D14, D15, D16, D17, D18, D19, D20, D21, D22, D23, D24: RED; LED-0603
E$1, E$2, E$3, E$4: FIDUCIAL-1X2
E$5, E$6: FIDUCIAL-1.5X3
FD1, FD2, FD3, FD4, FD5, FD6, FD7, FD8, FD9, FD10, FD11, FD12, FD13, FD14, FD15, FD16, FD17, FD18, FD19, FD20, FD21, FD22, FD23, FD24, FD25, FD26, FD27, FD28, FD29, FD30, FD31, FD32, FD33, FD34, FD35, FD36, FD37, FD38, FD39, FD40, FD41, FD42, FD43, FD44, FD45, FD46, FD47, FD48, FD49, FD50, FD51, FD52, FD53, FD54, FD55, FD56, FD57, FD58, FD59, FD60, FD61, FD62, FD63, FD64, FD65, FD66, FD67, FD68, FD69, FD70, FD71, FD72, FD73, FD74, FD75, FD76, FD77, FD78, FD79, FD80, FD81, FD82, FD83, FD84, FD85, FD86, FD87, FD88, FD89, FD90, FD91, FD92, FD93, FD94, FD95, FD96: FIDUCIAL1X2; FIDUCIAL-1X2
H1, H2, H3, H4, H5, H6, H7, H8, H9, H10, H11, H12, H13, H14, H15, H16, H17, H18, H19, H20, H21, H22, H23, H24, H25, H26, H27, H28, H29, H30, H31, H32, H33, H34, H35, H36, H37, H38, H39, H40, H41, H42, H43, H44, H45, H46, H47, H48, H49, H50, H51, H52, H53, H54, H55, H56, H57, H58, H59, H60, H61, H62, H63, H64, H65, H66, H67, H68, H69, H70, H71, H72, H73, H74, H75, H76, H77, H78, H79, H80, H81, H82, H83, H84, H85, H86, H87, H88, H89, H90, H91, H92, H93, H94, H95, H96: STAND-OFF
I2C, I2C1, I2C2, I2C3, I2C4, I2C5, I2C6, I2C7, I2C8, I2C9, I2C10, I2C11, I2C12, I2C13, I2C14, I2C15, I2C16, I2C17, I2C18, I2C19, I2C20, I2C21, I2C22, I2C23: JUMPER-SMT_3_2-NC_TRACE_SILK; SMT-JUMPER_3_2-NC_TRACE_SILK
J1, J2, J5, J6, J9, J10, J13, J14, J17, J18, J21, J22, J25, J26, J29, J30, J33, J34, J37, J38, J41, J42, J45, J46, J49, J50, J53, J54, J57, J58, J61, J62, J65, J66, J69, J70, J73, J74, J77, J78, J81, J82, J85, J86, J89, J90, J93, J94: QWIIC_RIGHT_ANGLE; JST04_1MM_RA
J3, J7, J11, J15, J19, J23, J27, J31, J35, J39, J43, J47, J51, J55, J59, J63, J67, J71, J75, J79, J83, J87, J91, J95: 1X06_NO_SILK
J4, J8, J12, J16, J20, J24, J28, J32, J36, J40, J44, J48, J52, J56, J60, J64, J68, J72, J76, J80, J84, J88, J92, J96: 1X02_NO_SILK
LOGO1, LOGO4, LOGO7, LOGO10, LOGO13, LOGO16, LOGO19, LOGO22, LOGO25, LOGO28, LOGO31, LOGO34, LOGO37, LOGO40, LOGO43, LOGO46, LOGO49, LOGO52, LOGO55, LOGO58, LOGO61, LOGO64, LOGO67, LOGO70: QWIIC_LOGO_5MM; QWIIC_5MM
LOGO2, LOGO5, LOGO8, LOGO11, LOGO14, LOGO17, LOGO20, LOGO23, LOGO26, LOGO29, LOGO32, LOGO35, LOGO38, LOGO41, LOGO44, LOGO47, LOGO50, LOGO53, LOGO56, LOGO59, LOGO62, LOGO65, LOGO68, LOGO71: SFE_LOGO_NAME_FLAME.1_INCH; SFE_LOGO_NAME_FLAME_.1
LOGO3, LOGO6, LOGO9, LOGO12, LOGO15, LOGO18, LOGO21, LOGO24, LOGO27, LOGO30, LOGO33, LOGO36, LOGO39, LOGO42, LOGO45, LOGO48, LOGO51, LOGO54, LOGO57, LOGO60, LOGO63, LOGO66, LOGO69, LOGO72: OSHW-LOGOS; OSHW-LOGO-S
PWR, PWR1, PWR2, PWR3, PWR4, PWR5, PWR6, PWR7, PWR8, PWR9, PWR10, PWR11, PWR12, PWR13, PWR14, PWR15, PWR16, PWR17, PWR18, PWR19, PWR20, PWR21, PWR22, PWR23: JUMPER-SMT_2_NC_TRACE_SILK; SMT-JUMPER_2_NC_TRACE_SILK
R1, R7, R13, R19, R25, R31, R37, R43, R49, R55, R61, R67, R73, R79, R85, R91, R97, R103, R109, R115, R121, R127, R133, R139: 1k; 0603
R2, R3, R8, R9, R14, R15, R20, R21, R26, R27, R32, R33, R38, R39, R44, R45, R50, R51, R56, R57, R62, R63, R68, R69, R74, R75, R80, R81, R86, R87, R92, R93, R98, R99, R104, R105, R110, R111, R116, R117, R122, R123, R128, R129, R134, R135, R140, R141: 2.2k; 0603
R4, R5, R6, R10, R11, R12, R16, R17, R18, R22, R23, R24, R28, R29, R30, R34, R35, R36, R40, R41, R42, R46, R47, R48, R52, R53, R54, R58, R59, R60, R64, R65, R66, R70, R71, R72, R76, R77, R78, R82, R83, R84, R88, R89, R90, R94, R95, R96, R100, R101, R102, R106, R107, R108, R112, R113, R114, R118, R119, R120, R124, R125, R126, R130, R131, R132, R136, R137, R138, R142, R143, R144: 10k; 0603
U1, U2, U3, U4, U5, U6, U7, U8, U9, U10, U11, U12, U13, U14, U15, U16, U17, U18, U19, U20, U21, U22, U23, U24: BMA400
U$1, U$30, U$65, U$97, U$129, U$161, U$193, U$225, U$257, U$289, U$321, U$353, U$385, U$417, U$449, U$481, U$513, U$545, U$577, U$609, U$641, U$673, U$705, U$737: PWR0
U$2, U$34, U$59, U$62, U$91, U$94, U$123, U$126, U$155, U$158, U$187, U$190, U$219, U$222, U$251, U$254, U$283, U$286, U$315, U$318, U$347, U$350, U$379, U$382, U$411, U$414, U$443, U$446, U$475, U$478, U$507, U$510, U$539, U$542, U$571, U$574, U$603, U$606, U$635, U$638, U$667, U$670, U$699, U$702, U$731, U$734, U$763, U$766: X2114
U$3, U$35, U$60, U$63, U$92, U$95, U$124, U$127, U$156, U$159, U$188, U$191, U$220, U$223, U$252, U$255, U$284, U$287, U$316, U$319, U$348, U$351, U$380, U$383, U$412, U$415, U$444, U$447, U$476, U$479, U$508, U$511, U$540, U$543, U$572, U$575, U$604, U$607, U$636, U$639, U$668, U$671, U$700, U$703, U$732, U$735, U$764, U$767: Y2115
U$4, U$20, U$31, U$46, U$66, U$78, U$98, U$110, U$130, U$142, U$162, U$174, U$194, U$206, U$226, U$238, U$258, U$270, U$290, U$302, U$322, U$334, U$354, U$366, U$386, U$398, U$418, U$430, U$450, U$462, U$482, U$494, U$514, U$526, U$546, U$558, U$578, U$590, U$610, U$622, U$642, U$654, U$674, U$686, U$706, U$718, U$738, U$750: #INT1_#0
U$5, U$21, U$32, U$47, U$67, U$79, U$99, U$111, U$131, U$143, U$163, U$175, U$195, U$207, U$227, U$239, U$259, U$271, U$291, U$303, U$323, U$335, U$355, U$367, U$387, U$399, U$419, U$431, U$451, U$463, U$483, U$495, U$515, U$527, U$547, U$559, U$579, U$591, U$611, U$623, U$643, U$655, U$675, U$687, U$707, U$719, U$739, U$751: #INT2_#0
U$6, U$57, U$89, U$121, U$153, U$185, U$217, U$249, U$281, U$313, U$345, U$377, U$409, U$441, U$473, U$505, U$537, U$569, U$601, U$633, U$665, U$697, U$729, U$761: #_3V3#6
U$7, U$56, U$88, U$120, U$152, U$184, U$216, U$248, U$280, U$312, U$344, U$376, U$408, U$440, U$472, U$504, U$536, U$568, U$600, U$632, U$664, U$696, U$728, U$760: #_SDA#PICO#5
U$8, U$54, U$86, U$118, U$150, U$182, U$214, U$246, U$278, U$310, U$342, U$374, U$406, U$438, U$470, U$502, U$534, U$566, U$598, U$630, U$662, U$694, U$726, U$758: #_#CS##2
U$9, U$55, U$87, U$119, U$151, U$183, U$215, U$247, U$279, U$311, U$343, U$375, U$407, U$439, U$471, U$503, U$535, U$567, U$599, U$631, U$663, U$695, U$727, U$759: #_SCL#SCK#3
U$10, U$33, U$68, U$100, U$132, U$164, U$196, U$228, U$260, U$292, U$324, U$356, U$388, U$420, U$452, U$484, U$516, U$548, U$580, U$612, U$644, U$676, U$708, U$740: #_GND#0
U$11, U$37, U$69, U$101, U$133, U$165, U$197, U$229, U$261, U$293, U$325, U$357, U$389, U$421, U$453, U$485, U$517, U$549, U$581, U$613, U$645, U$677, U$709, U$741: #_3V3#0
U$12, U$38, U$70, U$102, U$134, U$166, U$198, U$230, U$262, U$294, U$326, U$358, U$390, U$422, U$454, U$486, U$518, U$550, U$582, U$614, U$646, U$678, U$710, U$742: #_SDA#PICO#0
U$13, U$39, U$71, U$103, U$135, U$167, U$199, U$231, U$263, U$295, U$327, U$359, U$391, U$423, U$455, U$487, U$519, U$551, U$583, U$615, U$647, U$679, U$711, U$743: #_SCL#SCK#0
U$14, U$40, U$72, U$104, U$136, U$168, U$200, U$232, U$264, U$296, U$328, U$360, U$392, U$424, U$456, U$488, U$520, U$552, U$584, U$616, U$648, U$680, U$712, U$744: #_ADR#POCI#0
U$15, U$41, U$73, U$105, U$137, U$169, U$201, U$233, U$265, U$297, U$329, U$361, U$393, U$425, U$457, U$489, U$521, U$553, U$585, U$617, U$649, U$681, U$713, U$745: #_#CS##0
U$16, U$42, U$74, U$106, U$138, U$170, U$202, U$234, U$266, U$298, U$330, U$362, U$394, U$426, U$458, U$490, U$522, U$554, U$586, U$618, U$650, U$682, U$714, U$746: #I2C#0
U$17, U$43, U$75, U$107, U$139, U$171, U$203, U$235, U$267, U$299, U$331, U$363, U$395, U$427, U$459, U$491, U$523, U$555, U$587, U$619, U$651, U$683, U$715, U$747: #ADR#0
U$18, U$44, U$76, U$108, U$140, U$172, U$204, U$236, U$268, U$300, U$332, U$364, U$396, U$428, U$460, U$492, U$524, U$556, U$588, U$620, U$652, U$684, U$716, U$748: #0X15#0
U$19, U$45, U$77, U$109, U$141, U$173, U$205, U$237, U$269, U$301, U$333, U$365, U$397, U$429, U$461, U$493, U$525, U$557, U$589, U$621, U$653, U$685, U$717, U$749: #0X14#0
U$22, U$48, U$80, U$112, U$144, U$176, U$208, U$240, U$272, U$304, U$336, U$368, U$400, U$432, U$464, U$496, U$528, U$560, U$592, U$624, U$656, U$688, U$720, U$752: #PWR#0
U$23, U$24, U$49, U$50, U$81, U$82, U$113, U$114, U$145, U$146, U$177, U$178, U$209, U$210, U$241, U$242, U$273, U$274, U$305, U$306, U$337, U$338, U$369, U$370, U$401, U$402, U$433, U$434, U$465, U$466, U$497, U$498, U$529, U$530, U$561, U$562, U$593, U$594, U$625, U$626, U$657, U$658, U$689, U$690, U$721, U$722, U$753, U$754: BMA4000
U$25, U$51, U$83, U$115, U$147, U$179, U$211, U$243, U$275, U$307, U$339, U$371, U$403, U$435, U$467, U$499, U$531, U$563, U$595, U$627, U$659, U$691, U$723, U$755: ##CS##0
U$26, U$52, U$84, U$116, U$148, U$180, U$212, U$244, U$276, U$308, U$340, U$372, U$404, U$436, U$468, U$500, U$532, U$564, U$596, U$628, U$660, U$692, U$724, U$756: SFE_LOGO_FLAME_.1
U$27, U$53, U$85, U$117, U$149, U$181, U$213, U$245, U$277, U$309, U$341, U$373, U$405, U$437, U$469, U$501, U$533, U$565, U$597, U$629, U$661, U$693, U$725, U$757: #_ADR#POCI#1
U$28, U$58, U$90, U$122, U$154, U$186, U$218, U$250, U$282, U$314, U$346, U$378, U$410, U$442, U$474, U$506, U$538, U$570, U$602, U$634, U$666, U$698, U$730, U$762: #_GND#6
U$29, U$36, U$61, U$64, U$93, U$96, U$125, U$128, U$157, U$160, U$189, U$192, U$221, U$224, U$253, U$256, U$285, U$288, U$317, U$320, U$349, U$352, U$381, U$384, U$413, U$416, U$445, U$448, U$477, U$480, U$509, U$512, U$541, U$544, U$573, U$576, U$605, U$608, U$637, U$640, U$669, U$672, U$701, U$704, U$733, U$736, U$765, U$768: Z2116

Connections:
3.3V: !CS!.2, C1.1, C2.1, I2C.2, J1.2, J2.2, J3.2, PWR.2, R5.2, U1.3, U1.7
3.3V1: !CS!1.2, C3.1, C4.1, I2C1.2, J5.2, J6.2, J7.2, PWR1.2, R11.2, U2.3, U2.7
3.3V2: !CS!2.2, C5.1, C6.1, I2C2.2, J9.2, J10.2, J11.2, PWR2.2, R17.2, U3.3, U3.7
3.3V3: !CS!3.2, C7.1, C8.1, I2C3.2, J13.2, J14.2, J15.2, PWR3.2, R23.2, U4.3, U4.7
3.3V4: !CS!4.2, C9.1, C10.1, I2C4.2, J17.2, J18.2, J19.2, PWR4.2, R29.2, U5.3, U5.7
3.3V5: !CS!5.2, C11.1, C12.1, I2C5.2, J21.2, J22.2, J23.2, PWR5.2, R35.2, U6.3, U6.7
3.3V6: !CS!6.2, C13.1, C14.1, I2C6.2, J25.2, J26.2, J27.2, PWR6.2, R41.2, U7.3, U7.7
3.3V7: !CS!7.2, C15.1, C16.1, I2C7.2, J29.2, J30.2, J31.2, PWR7.2, R47.2, U8.3, U8.7
3.3V8: !CS!8.2, C17.1, C18.1, I2C8.2, J33.2, J34.2, J35.2, PWR8.2, R53.2, U9.3, U9.7
3.3V9: !CS!9.2, C19.1, C20.1, I2C9.2, J37.2, J38.2, J39.2, PWR9.2, R59.2, U10.3, U10.7
3.3V10: !CS!10.2, C21.1, C22.1, I2C10.2, J41.2, J42.2, J43.2, PWR10.2, R65.2, U11.3, U11.7
3.3V11: !CS!11.2, C23.1, C24.1, I2C11.2, J45.2, J46.2, J47.2, PWR11.2, R71.2, U12.3, U12.7
3.3V12: !CS!12.2, C25.1, C26.1, I2C12.2, J49.2, J50.2, J51.2, PWR12.2, R77.2, U13.3, U13.7
3.3V13: !CS!13.2, C27.1, C28.1, I2C13.2, J53.2, J54.2, J55.2, PWR13.2, R83.2, U14.3, U14.7
3.3V14: !CS!14.2, C29.1, C30.1, I2C14.2, J57.2, J58.2, J59.2, PWR14.2, R89.2, U15.3, U15.7
3.3V15: !CS!15.2, C31.1, C32.1, I2C15.2, J61.2, J62.2, J63.2, PWR15.2, R95.2, U16.3, U16.7
3.3V16: !CS!16.2, C33.1, C34.1, I2C16.2, J65.2, J66.2, J67.2, PWR16.2, R101.2, U17.3, U17.7
3.3V17: !CS!17.2, C35.1, C36.1, I2C17.2, J69.2, J70.2, J71.2, PWR17.2, R107.2, U18.3, U18.7
3.3V18: !CS!18.2, C37.1, C38.1, I2C18.2, J73.2, J74.2, J75.2, PWR18.2, R113.2, U19.3, U19.7
3.3V19: !CS!19.2, C39.1, C40.1, I2C19.2, J77.2, J78.2, J79.2, PWR19.2, R119.2, U20.3, U20.7
3.3V20: !CS!20.2, C41.1, C42.1, I2C20.2, J81.2, J82.2, J83.2, PWR20.2, R125.2, U21.3, U21.7
3.3V21: !CS!21.2, C43.1, C44.1, I2C21.2, J85.2, J86.2, J87.2, PWR21.2, R131.2, U22.3, U22.7
3.3V22: !CS!22.2, C45.1, C46.1, I2C22.2, J89.2, J90.2, J91.2, PWR22.2, R137.2, U23.3, U23.7
3.3V23: !CS!23.2, C47.1, C48.1, I2C23.2, J93.2, J94.2, J95.2, PWR23.2, R143.2, U24.3, U24.7
!CS!: J3.6, R6.1, U1.10
!CS!1: J7.6, R12.1, U2.10
!CS!2: J11.6, R18.1, U3.10
!CS!3: J15.6, R24.1, U4.10
!CS!4: J19.6, R30.1, U5.10
!CS!5: J23.6, R36.1, U6.10
!CS!6: J27.6, R42.1, U7.10
!CS!7: J31.6, R48.1, U8.10
!CS!8: J35.6, R54.1, U9.10
!CS!9: J39.6, R60.1, U10.10
!CS!10: J43.6, R66.1, U11.10
!CS!11: J47.6, R72.1, U12.10
!CS!12: J51.6, R78.1, U13.10
!CS!13: J55.6, R84.1, U14.10
!CS!14: J59.6, R90.1, U15.10
!CS!15: J63.6, R96.1, U16.10
!CS!16: J67.6, R102.1, U17.10
!CS!17: J71.6, R108.1, U18.10
!CS!18: J75.6, R114.1, U19.10
!CS!19: J79.6, R120.1, U20.10
!CS!20: J83.6, R126.1, U21.10
!CS!21: J87.6, R132.1, U22.10
!CS!22: J91.6, R138.1, U23.10
!CS!23: J95.6, R144.1, U24.10
ADR/POCI: ADR.2, J3.5, U1.1
ADR/POCI1: ADR1.2, J7.5, U2.1
ADR/POCI2: ADR2.2, J11.5, U3.1
ADR/POCI3: ADR3.2, J15.5, U4.1
ADR/POCI4: ADR4.2, J19.5, U5.1
ADR/POCI5: ADR5.2, J23.5, U6.1
ADR/POCI6: ADR6.2, J27.5, U7.1
ADR/POCI7: ADR7.2, J31.5, U8.1
ADR/POCI8: ADR8.2, J35.5, U9.1
ADR/POCI9: ADR9.2, J39.5, U10.1
ADR/POCI10: ADR10.2, J43.5, U11.1
ADR/POCI11: ADR11.2, J47.5, U12.1
ADR/POCI12: ADR12.2, J51.5, U13.1
ADR/POCI13: ADR13.2, J55.5, U14.1
ADR/POCI14: ADR14.2, J59.5, U15.1
ADR/POCI15: ADR15.2, J63.5, U16.1
ADR/POCI16: ADR16.2, J67.5, U17.1
ADR/POCI17: ADR17.2, J71.5, U18.1
ADR/POCI18: ADR18.2, J75.5, U19.1
ADR/POCI19: ADR19.2, J79.5, U20.1
ADR/POCI20: ADR20.2, J83.5, U21.1
ADR/POCI21: ADR21.2, J87.5, U22.1
ADR/POCI22: ADR22.2, J91.5, U23.1
ADR/POCI23: ADR23.2, J95.5, U24.1
GND: C1.2, C2.2, J1.1, J2.1, J3.1, R1.1, R4.1, U1.8, U1.9
GND1: C3.2, C4.2, J5.1, J6.1, J7.1, R7.1, R10.1, U2.8, U2.9
GND2: C5.2, C6.2, J9.1, J10.1, J11.1, R13.1, R16.1, U3.8, U3.9
GND3: C7.2, C8.2, J13.1, J14.1, J15.1, R19.1, R22.1, U4.8, U4.9
GND4: C9.2, C10.2, J17.1, J18.1, J19.1, R25.1, R28.1, U5.8, U5.9
GND5: C11.2, C12.2, J21.1, J22.1, J23.1, R31.1, R34.1, U6.8, U6.9
GND6: C13.2, C14.2, J25.1, J26.1, J27.1, R37.1, R40.1, U7.8, U7.9
GND7: C15.2, C16.2, J29.1, J30.1, J31.1, R43.1, R46.1, U8.8, U8.9
GND8: C17.2, C18.2, J33.1, J34.1, J35.1, R49.1, R52.1, U9.8, U9.9
GND9: C19.2, C20.2, J37.1, J38.1, J39.1, R55.1, R58.1, U10.8, U10.9
GND10: C21.2, C22.2, J41.1, J42.1, J43.1, R61.1, R64.1, U11.8, U11.9
GND11: C23.2, C24.2, J45.1, J46.1, J47.1, R67.1, R70.1, U12.8, U12.9
GND12: C25.2, C26.2, J49.1, J50.1, J51.1, R73.1, R76.1, U13.8, U13.9
GND13: C27.2, C28.2, J53.1, J54.1, J55.1, R79.1, R82.1, U14.8, U14.9
GND14: C29.2, C30.2, J57.1, J58.1, J59.1, R85.1, R88.1, U15.8, U15.9
GND15: C31.2, C32.2, J61.1, J62.1, J63.1, R91.1, R94.1, U16.8, U16.9
GND16: C33.2, C34.2, J65.1, J66.1, J67.1, R97.1, R100.1, U17.8, U17.9
GND17: C35.2, C36.2, J69.1, J70.1, J71.1, R103.1, R106.1, U18.8, U18.9
GND18: C37.2, C38.2, J73.1, J74.1, J75.1, R109.1, R112.1, U19.8, U19.9
GND19: C39.2, C40.2, J77.1, J78.1, J79.1, R115.1, R118.1, U20.8, U20.9
GND20: C41.2, C42.2, J81.1, J82.1, J83.1, R121.1, R124.1, U21.8, U21.9
GND21: C43.2, C44.2, J85.1, J86.1, J87.1, R127.1, R130.1, U22.8, U22.9
GND22: C45.2, C46.2, J89.1, J90.1, J91.1, R133.1, R136.1, U23.8, U23.9
GND23: C47.2, C48.2, J93.1, J94.1, J95.1, R139.1, R142.1, U24.8, U24.9
INT1: J4.1, U1.5
INT2: J4.2, U1.6
INT3: J8.1, U2.5
INT4: J8.2, U2.6
INT5: J12.1, U3.5
INT6: J12.2, U3.6
INT7: J16.1, U4.5
INT8: J16.2, U4.6
INT9: J20.1, U5.5
INT10: J20.2, U5.6
INT11: J24.1, U6.5
INT12: J24.2, U6.6
INT13: J28.1, U7.5
INT14: J28.2, U7.6
INT15: J32.1, U8.5
INT16: J32.2, U8.6
INT17: J36.1, U9.5
INT18: J36.2, U9.6
INT19: J40.1, U10.5
INT20: J40.2, U10.6
INT21: J44.1, U11.5
INT22: J44.2, U11.6
INT23: J48.1, U12.5
INT24: J48.2, U12.6
INT25: J52.1, U13.5
INT26: J52.2, U13.6
INT27: J56.1, U14.5
INT28: J56.2, U14.6
INT29: J60.1, U15.5
INT30: J60.2, U15.6
INT31: J64.1, U16.5
INT32: J64.2, U16.6
INT33: J68.1, U17.5
INT34: J68.2, U17.6
INT35: J72.1, U18.5
INT36: J72.2, U18.6
INT37: J76.1, U19.5
INT38: J76.2, U19.6
INT39: J80.1, U20.5
INT40: J80.2, U20.6
INT41: J84.1, U21.5
INT42: J84.2, U21.6
INT43: J88.1, U22.5
INT44: J88.2, U22.6
INT45: J92.1, U23.5
INT46: J92.2, U23.6
INT47: J96.1, U24.5
INT48: J96.2, U24.6
unnamed: D1.A, PWR.1
unnamed: D1.C, R1.2
unnamed: I2C.3, R2.2
unnamed: I2C.1, R3.1
unnamed: ADR.1, R5.1
unnamed: ADR.3, R4.2
unnamed: !CS!.1, R6.2
unnamed: D2.C, R7.2
unnamed: I2C1.3, R8.2
unnamed: I2C1.1, R9.1
unnamed: ADR1.1, R11.1
unnamed: ADR1.3, R10.2
unnamed: D2.A, PWR1.1
unnamed: !CS!1.1, R12.2
unnamed: D3.C, R13.2
unnamed: I2C2.3, R14.2
unnamed: I2C2.1, R15.1
unnamed: ADR2.1, R17.1
unnamed: ADR2.3, R16.2
unnamed: D3.A, PWR2.1
unnamed: !CS!2.1, R18.2
unnamed: D4.C, R19.2
unnamed: I2C3.3, R20.2
unnamed: I2C3.1, R21.1
unnamed: ADR3.1, R23.1
unnamed: ADR3.3, R22.2
unnamed: D4.A, PWR3.1
unnamed: !CS!3.1, R24.2
unnamed: D5.C, R25.2
unnamed: I2C4.3, R26.2
unnamed: I2C4.1, R27.1
unnamed: ADR4.1, R29.1
unnamed: ADR4.3, R28.2
unnamed: D5.A, PWR4.1
unnamed: !CS!4.1, R30.2
unnamed: D6.C, R31.2
unnamed: I2C5.3, R32.2
unnamed: I2C5.1, R33.1
unnamed: ADR5.1, R35.1
unnamed: ADR5.3, R34.2
unnamed: D6.A, PWR5.1
unnamed: !CS!5.1, R36.2
unnamed: D7.C, R37.2
unnamed: I2C6.3, R38.2
unnamed: I2C6.1, R39.1
unnamed: ADR6.1, R41.1
unnamed: ADR6.3, R40.2
unnamed: D7.A, PWR6.1
unnamed: !CS!6.1, R42.2
unnamed: D8.C, R43.2
unnamed: I2C7.3, R44.2
unnamed: I2C7.1, R45.1
unnamed: ADR7.1, R47.1
unnamed: ADR7.3, R46.2
unnamed: D8.A, PWR7.1
unnamed: !CS!7.1, R48.2
unnamed: D9.C, R49.2
unnamed: I2C8.3, R50.2
unnamed: I2C8.1, R51.1
unnamed: ADR8.1, R53.1
unnamed: ADR8.3, R52.2
unnamed: D9.A, PWR8.1
unnamed: !CS!8.1, R54.2
unnamed: D10.C, R55.2
unnamed: I2C9.3, R56.2
unnamed: I2C9.1, R57.1
unnamed: ADR9.1, R59.1
unnamed: ADR9.3, R58.2
unnamed: D10.A, PWR9.1
unnamed: !CS!9.1, R60.2
unnamed: D11.C, R61.2
unnamed: I2C10.3, R62.2
unnamed: I2C10.1, R63.1
unnamed: ADR10.1, R65.1
unnamed: ADR10.3, R64.2
unnamed: D11.A, PWR10.1
unnamed: !CS!10.1, R66.2
unnamed: D12.C, R67.2
unnamed: I2C11.3, R68.2
unnamed: I2C11.1, R69.1
unnamed: ADR11.1, R71.1
unnamed: ADR11.3, R70.2
unnamed: D12.A, PWR11.1
unnamed: !CS!11.1, R72.2
unnamed: D13.C, R73.2
unnamed: I2C12.3, R74.2
unnamed: I2C12.1, R75.1
unnamed: ADR12.1, R77.1
unnamed: ADR12.3, R76.2
unnamed: D13.A, PWR12.1
unnamed: !CS!12.1, R78.2
unnamed: D14.C, R79.2
unnamed: I2C13.3, R80.2
unnamed: I2C13.1, R81.1
unnamed: ADR13.1, R83.1
unnamed: ADR13.3, R82.2
unnamed: D14.A, PWR13.1
unnamed: !CS!13.1, R84.2
unnamed: D15.C, R85.2
unnamed: I2C14.3, R86.2
unnamed: I2C14.1, R87.1
unnamed: ADR14.1, R89.1
unnamed: ADR14.3, R88.2
unnamed: D15.A, PWR14.1
unnamed: !CS!14.1, R90.2
unnamed: D16.C, R91.2
unnamed: I2C15.3, R92.2
unnamed: I2C15.1, R93.1
unnamed: ADR15.1, R95.1
unnamed: ADR15.3, R94.2
unnamed: D16.A, PWR15.1
unnamed: !CS!15.1, R96.2
unnamed: D17.C, R97.2
unnamed: I2C16.3, R98.2
unnamed: I2C16.1, R99.1
unnamed: ADR16.1, R101.1
unnamed: ADR16.3, R100.2
unnamed: D17.A, PWR16.1
unnamed: !CS!16.1, R102.2
unnamed: D18.C, R103.2
unnamed: I2C17.3, R104.2
unnamed: I2C17.1, R105.1
unnamed: ADR17.1, R107.1
unnamed: ADR17.3, R106.2
unnamed: D18.A, PWR17.1
unnamed: !CS!17.1, R108.2
unnamed: D19.C, R109.2
unnamed: I2C18.3, R110.2
unnamed: I2C18.1, R111.1
unnamed: ADR18.1, R113.1
unnamed: ADR18.3, R112.2
unnamed: D19.A, PWR18.1
unnamed: !CS!18.1, R114.2
unnamed: D20.C, R115.2
unnamed: I2C19.3, R116.2
unnamed: I2C19.1, R117.1
unnamed: ADR19.1, R119.1
unnamed: ADR19.3, R118.2
unnamed: D20.A, PWR19.1
unnamed: !CS!19.1, R120.2
unnamed: D21.C, R121.2
unnamed: I2C20.3, R122.2
unnamed: I2C20.1, R123.1
unnamed: ADR20.1, R125.1
unnamed: ADR20.3, R124.2
unnamed: D21.A, PWR20.1
unnamed: !CS!20.1, R126.2
unnamed: D22.C, R127.2
unnamed: I2C21.3, R128.2
unnamed: I2C21.1, R129.1
unnamed: ADR21.1, R131.1
unnamed: ADR21.3, R130.2
unnamed: D22.A, PWR21.1
unnamed: !CS!21.1, R132.2
unnamed: D23.C, R133.2
unnamed: I2C22.3, R134.2
unnamed: I2C22.1, R135.1
unnamed: ADR22.1, R137.1
unnamed: ADR22.3, R136.2
unnamed: D23.A, PWR22.1
unnamed: !CS!22.1, R138.2
unnamed: D24.C, R139.2
unnamed: I2C23.3, R140.2
unnamed: I2C23.1, R141.1
unnamed: ADR23.1, R143.1
unnamed: ADR23.3, R142.2
unnamed: D24.A, PWR23.1
unnamed: !CS!23.1, R144.2
SCL/SCK: J1.4, J2.4, J3.4, R2.1, U1.12
SCL/SCK1: J5.4, J6.4, J7.4, R8.1, U2.12
SCL/SCK2: J9.4, J10.4, J11.4, R14.1, U3.12
SCL/SCK3: J13.4, J14.4, J15.4, R20.1, U4.12
SCL/SCK4: J17.4, J18.4, J19.4, R26.1, U5.12
SCL/SCK5: J21.4, J22.4, J23.4, R32.1, U6.12
SCL/SCK6: J25.4, J26.4, J27.4, R38.1, U7.12
SCL/SCK7: J29.4, J30.4, J31.4, R44.1, U8.12
SCL/SCK8: J33.4, J34.4, J35.4, R50.1, U9.12
SCL/SCK9: J37.4, J38.4, J39.4, R56.1, U10.12
SCL/SCK10: J41.4, J42.4, J43.4, R62.1, U11.12
SCL/SCK11: J45.4, J46.4, J47.4, R68.1, U12.12
SCL/SCK12: J49.4, J50.4, J51.4, R74.1, U13.12
SCL/SCK13: J53.4, J54.4, J55.4, R80.1, U14.12
SCL/SCK14: J57.4, J58.4, J59.4, R86.1, U15.12
SCL/SCK15: J61.4, J62.4, J63.4, R92.1, U16.12
SCL/SCK16: J65.4, J66.4, J67.4, R98.1, U17.12
SCL/SCK17: J69.4, J70.4, J71.4, R104.1, U18.12
SCL/SCK18: J73.4, J74.4, J75.4, R110.1, U19.12
SCL/SCK19: J77.4, J78.4, J79.4, R116.1, U20.12
SCL/SCK20: J81.4, J82.4, J83.4, R122.1, U21.12
SCL/SCK21: J85.4, J86.4, J87.4, R128.1, U22.12
SCL/SCK22: J89.4, J90.4, J91.4, R134.1, U23.12
SCL/SCK23: J93.4, J94.4, J95.4, R140.1, U24.12
SDA/PICO: J1.3, J2.3, J3.3, R3.2, U1.2
SDA/PICO1: J5.3, J6.3, J7.3, R9.2, U2.2
SDA/PICO2: J9.3, J10.3, J11.3, R15.2, U3.2
SDA/PICO3: J13.3, J14.3, J15.3, R21.2, U4.2
SDA/PICO4: J17.3, J18.3, J19.3, R27.2, U5.2
SDA/PICO5: J21.3, J22.3, J23.3, R33.2, U6.2
SDA/PICO6: J25.3, J26.3, J27.3, R39.2, U7.2
SDA/PICO7: J29.3, J30.3, J31.3, R45.2, U8.2
SDA/PICO8: J33.3, J34.3, J35.3, R51.2, U9.2
SDA/PICO9: J37.3, J38.3, J39.3, R57.2, U10.2
SDA/PICO10: J41.3, J42.3, J43.3, R63.2, U11.2
SDA/PICO11: J45.3, J46.3, J47.3, R69.2, U12.2
SDA/PICO12: J49.3, J50.3, J51.3, R75.2, U13.2
SDA/PICO13: J53.3, J54.3, J55.3, R81.2, U14.2
SDA/PICO14: J57.3, J58.3, J59.3, R87.2, U15.2
SDA/PICO15: J61.3, J62.3, J63.3, R93.2, U16.2
SDA/PICO16: J65.3, J66.3, J67.3, R99.2, U17.2
SDA/PICO17: J69.3, J70.3, J71.3, R105.2, U18.2
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

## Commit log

2022-09-13 Create initial 1x1 schematic and board
    [SparkFun_Qwiic_Accelerometer_BMA400.brd, SparkFun_Qwiic_Accelerometer_BMA400.sch]
2022-09-13 Create initial micro schematic and board
    [SparkFun_Qwiic_Micro_Accelerometer_BMA400.brd, SparkFun_Qwiic_Micro_Accelerometer_BMA400.sch]
2022-09-14 Design review updates
    Add BMA400 voltage range to schematics
    Add designer name to boards' tDocu
    Add measures to 1x1
    Adjust traces of micro
    [SparkFun_Qwiic_Accelerometer_BMA400.brd, SparkFun_Qwiic_Accelerometer_BMA400.sch, SparkFun_Qwiic_Micro_Accelerometer_BMA400.brd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]
2022-09-14 Design review updates
    Reduce silk labels on top side of 1x1
    Adjust position of "BMA400" top silk of Micro
    Rotate PWR jumper of Micro
    [SparkFun_Qwiic_Accelerometer_BMA400.brd, SparkFun_Qwiic_Micro_Accelerometer_BMA400.brd]
2022-09-14 Design review updates
    Fix I2C address table
    Add "default" to I2C address table
    Approve jumper overlap errors
    [SparkFun_Qwiic_Accelerometer_BMA400.brd, SparkFun_Qwiic_Accelerometer_BMA400.sch, SparkFun_Qwiic_Micro_Accelerometer_BMA400.brd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]
2022-09-14 Add units to measures
    [SparkFun_Qwiic_Accelerometer_BMA400.brd, SparkFun_Qwiic_Micro_Accelerometer_BMA400.brd]
2022-09-14 Change default I2C address
    [SparkFun_Qwiic_Accelerometer_BMA400.brd, SparkFun_Qwiic_Accelerometer_BMA400.sch, SparkFun_Qwiic_Micro_Accelerometer_BMA400.brd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]
2022-09-15 Add PROD_ID and description to BMA400
    [SparkFun_Qwiic_Accelerometer_BMA400.brd, SparkFun_Qwiic_Accelerometer_BMA400.sch, SparkFun_Qwiic_Micro_Accelerometer_BMA400.brd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]
2022-10-10 Add axes labels
    [SparkFun_Qwiic_Accelerometer_BMA400.brd, SparkFun_Qwiic_Accelerometer_BMA400.sch, SparkFun_Qwiic_Micro_Accelerometer_BMA400.brd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]
2022-10-10 Update version number to v10
    [SparkFun_Qwiic_Accelerometer_BMA400.brd, SparkFun_Qwiic_Accelerometer_BMA400.sch, SparkFun_Qwiic_Micro_Accelerometer_BMA400.brd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]
2022-10-13 Design review updates
    Move fiducials on Micro to be diagonal
    Add extra GND vias to Micro
    [SparkFun_Qwiic_Micro_Accelerometer_BMA400.brd]
2022-10-13 Add v10 production files
    [SparkFun_Qwiic_Accelerometer_BMA400-Panel.GBL, SparkFun_Qwiic_Accelerometer_BMA400-Panel.GBO, SparkFun_Qwiic_Accelerometer_BMA400-Panel.GBP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]
2022-10-20 Add text about 22AWG wires to Micro schematic
    [SparkFun_Qwiic_Micro_Accelerometer_BMA400.sch]
2023-03-28 Remove library file
    Part is in SFE Eagle library, update part in design
    [SparkFun_Qwiic_Accelerometer_BMA400.brd, SparkFun_Qwiic_Accelerometer_BMA400.sch, SparkFun_Qwiic_Micro_Accelerometer_BMA400.brd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]

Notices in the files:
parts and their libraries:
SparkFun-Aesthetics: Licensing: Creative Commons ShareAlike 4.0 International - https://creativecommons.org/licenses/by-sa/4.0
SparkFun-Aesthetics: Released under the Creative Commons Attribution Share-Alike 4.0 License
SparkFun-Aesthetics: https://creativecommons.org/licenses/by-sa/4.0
